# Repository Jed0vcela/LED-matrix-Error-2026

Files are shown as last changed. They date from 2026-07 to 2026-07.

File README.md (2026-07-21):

# LED Matrix Handheld — herní konzole s více hrami

Kapesní zařízení s LED maticí 32×16, postavené na Raspberry Pi Pico (RP2040)
s MicroPythonem. Samotné zařízení nabízí přes 20 vestavěných her a
pomůcek; víc zařízení lze propojit řetězcem po UART pro hry pro dva hráče
a sdílené režimy. K desce lze navíc připojit externí gamepad.
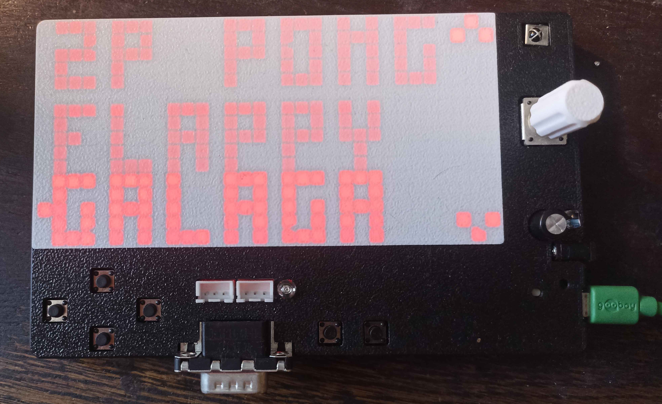
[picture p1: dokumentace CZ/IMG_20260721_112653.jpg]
popis obrázku


## Co to umí

- **20+ vestavěných her**: Snake, Breakout, uhýbačka ve stylu Flappy Bird,
  zjednodušená Galaga a Asteroids (obě s "megastřelou" po podržení
  tlačítka), Frogger, test reflexů, Missile Command, závodní uhýbač ve 4
  pruzích, běžecká hra ve stylu T-Rex se skutečnou skokovou fyzikou,
  paměťová hra ve stylu Simon a simulace rozvážejícího výtahu s plným
  rizikovým "MLG" režimem (detaily viz dokumentace firmware)
- **Podpora pro dva hráče** přes jednoduchý řetězec po UART — žádné
  párování, žádné adresování, stačí propojit zařízení TX→RX za sebou.
  Zahrnuje 2P Snake, 2P Pong, 2P Tron (light cycles) a sdílené 2P Malování /
  2P Game of Life
- **Pomůcky**: volné kreslení, Conwayova hra Life, hodiny, stopky, režim
  šetřiče displeje a nastavení (ruční nebo automatický jas podle
  světelného čidla, hodiny a přepínač zobrazení skóre po konci hry)
- **Senzory**: IR přijímač (vstup z dálkového ovladače, protokol NEC) a
  fotodioda (automatický jas podle okolního světla)
- **Externí gamepad** přes 9pinový D-sub konektor (pinout kompatibilní s
  Atari) — viz [HW.md](dokumentace%20CZ/HW.md)

## Návrhové nástroje

- **PCB** je nakreslené v [KiCad](https://www.kicad.org/) — je to zdarma a
  open-source, takže si projekt může kdokoliv doma otevřít, prohlédnout a
  upravit bez placené licence.
- **3D návrh** (krabička apod.) je vytvořený v Solidworks. Díly určené k
  3D tisku jsou ale exportované i jako `.STL` — to je běžný formát, se
  kterým si poradí prakticky jakýkoliv slicer/3D tiskárna, i bez Solidworks.

Detaily k oběma najdeš v [HW.md](dokumentace%20CZ/HW.md).

## Dokumentace

Kompletní rozpis každé hry a nastavení: **[FW_v1.0.md](dokumentace%20CZ/FW/v1.0/FW_v1.0.md)**

Zapojení, piny, gamepad a jak používat IR přijímač / fotodiodu:
**[HW.md](dokumentace%20CZ/HW.md)**

Popis podpůrných zdrojových souborů (co jde spustit samostatně, jak se dají
upravovat): **[ZDROJOVE_KODY.md](dokumentace%20CZ/ZDROJOVE_KODY.md)**

## Jak začít

1. **Nainstaluj Thonny** (IDE, kterým se kód MicroPythonu píše/nahrává do
   zařízení): [thonny.org](https://thonny.org/)
2. **Nahraj firmware do zařízení**: 
   [Jak nahrát soubory do zařízení (YouTube)](https://youtu.be/NCa7N6zXSKU?si=G6rsxXgdZRCBtUNG)
3. Pokud si stavíš vlastní zařízení od nuly, zapoj hardware podle
   **[HW.md](dokumentace%20CZ/HW.md)**.
4. Pro hry pro dva hráče propoj UART druhého zařízení podle
   [HW.md](dokumentace%20CZ/HW.md#propojení-pro-více-hráčů-řetězec) a zapni
   obě zařízení.

## Struktura repozitáře

```
README.md                          <- tenhle soubor (v rootu)
dokumentace CZ/
  HW.md                            <- zapojení hardwaru, gamepad, PCB/3D, IR/fotodioda
  ZDROJOVE_KODY.md                 <- popis podpůrných zdrojových souborů
  obrazky/                         <- obrázky použité v .md souborech
  FW/
    v1.0/
      FW_v1.0.md                   <- kompletní dokumentace firmware v1.0
    v1.1/ (do budoucna)
      FW_v1.1.md
main.py                            <- zdrojový kód firmware (doplnit / dle verze)
```

Každá verze firmware má vlastní složku a vlastní dokumentaci, takže i starší
verze zůstanou zdokumentované i po přidání novějších. Mezi jednotlivými
`.md` soubory se dá procházet přes odkazy přímo v textu.

## Aktuální verze firmware

**v1.0** — kompletní dokumentace her a nastavení je v
[FW_v1.0.md](dokumentace%20CZ/FW/v1.0/FW_v1.0.md).

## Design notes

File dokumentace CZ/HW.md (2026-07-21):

[⬅ Zpět na README](../README.md) · [Dokumentace firmware v1.0 →](FW/v1.0/FW_v1.0.md) · [Popis zdrojových souborů →](ZDROJOVE_KODY.md)

# Hardwarová dokumentace

Popisuje fyzické zapojení, návrhové nástroje a dvě "chytré" periferie (IR
přijímač a fotodioda).

## Přehled

- **Mikrokontrolér**: Raspberry Pi Pico / RP2040, MicroPython
- **Displej**: LED matice 32×16, multiplexovaná, řízená přes PIO (viz níže)
- **Vstup**: 6 tlačítek (nahoru, dolů, vlevo, vpravo, Fire1, Fire2) +
  1 rotační enkodér se vestavěným tlačítkem, plus volitelný externí gamepad
- **Propojení pro více hráčů**: řetězec (daisy-chain) po UART mezi zařízeními
  (viz níže)
- **Navíc**: IR přijímač (dálkové ovládání, protokol NEC), fotodioda
  (měření okolního světla pro automatický jas), reálný čas (interní RTC
  RP2040 přes `machine.RTC()`)

## Návrhové nástroje

- **PCB** je nakreslené v **KiCad**. KiCad je zdarma a open-source, takže
  projekt (schéma i desku) může kdokoliv otevřít doma, prohlédnout si ho a
  rovnou upravit — není potřeba žádná placená licence ani export do
  proprietárního formátu.
- **3D návrh** (krabička, mechanické díly) je nakreslený v **Solidworks**.
  Díly určené k 3D tisku jsou ale exportované i jako **`.STL`** — to je
  standardní formát pro 3D tisk, který přečte prakticky každý slicer i bez
  Solidworks.

## Co je GPIO

GPIO ("General Purpose Input/Output") je obecný digitální pin
mikrokontroléru, který jde v softwaru nastavit jako vstup nebo výstup a číst
z něj/zapisovat do něj logickou 0 nebo 1. Některé GPIO piny na RP2040 mají
navíc i **ADC** funkci — umí kromě digitálního 0/1 změřit i analogové napětí
(0–3,3 V). Právě tahle dvojí schopnost (digitální i analogové čtení na
stejném fyzickém pinu) je důvod, proč je GP27 níže v tabulce zajímavý — dá
se použít jak na jednoduché zapnuto/vypnuto ovládání něčeho externího, tak
na měření analogové úrovně nějakého vnějšího signálu.

## Kompletní zapojení pinů (RP2040)

| Pin | Funkce |
|---|---|
| GP0 | IR_RX (IR přijímač) |
| GP1 | row_latch |
| GP2 | row_clk |
| GP3 | row_mosi |
| GP4 | encoder B |
| GP5 | IR_TX (IR vysílač) |
| GP6 | encoder A |
| GP7 | Iset1 (LSB pro řízení jasu displeje) |
| GP8 | TX (pro multiplayer) |
| GP9 | RX (pro multiplayer) |
| GP10 | Iset2 (pro řízení jasu displeje) |
| GP11 | Iset3 (MSB pro řízení jasu displeje) |
| GP12 | LATCH (pro shift register sloupců) |
| GP13 | OE (output enable pro shift register sloupců) |
| GP14 | CLK (pro shift register sloupců) |
| GP15 | MOSI (pro shift register sloupců) |
| GP16 | button1 / fire1 (aktivní v log. 0) |
| GP17 | right (aktivní v log. 0) |
| GP18 | left (aktivní v log. 0) |
| GP19 | down (aktivní v log. 0) |
| GP20 | up (aktivní v log. 0) |
| GP21 | button2 / fire2 (aktivní v log. 0) |
| GP22 | tlačítko enkodéru |
| GP25 | onboard LED (bliká souběžně s přijímaným IR signálem, jen pro ladění) |
| GP26 | volný pin |
| GP27 | vyvedeno na 9pinový D-sub, umí digitální i ADC — viz sekce o gamepadu níže |
| GP28 | ADC, připojeno na fotodiodu — viz sekce o fotodiodě níže |

Tlačítka (GP16–GP21, GP22) se čtou jako **aktivní v log. 0** (stisknuto =
pin čte 0) — jsou tedy zapojená s pull-upem a spínačem, který při stisku
stáhne pin na zem.

Pár doplňujících technických detailů k vybraným pinům:

- **GP0** (IR přijímač) — digitální vstup, běžný IR demodulátor na 38 kHz
- **GP28** (fotodioda) — jde o ADC kanál **ADC2**
- **GP8/GP9** (řetězec pro více hráčů) — UART1, 115200 baud, 8N1

⚠️ **Známá chyba v návrhu desky**: rotační enkodér se při návrhu omylem
zapomněl připojit k Raspberry Pi Pico, takže se musel na hotové desce
zapojit ručně (mimo původní návrh DPS). Zapojení podle tabulky výše (GP4 =
B, GP6 = A, GP22 = tlačítko) ale odpovídá tomu, jak je to nakonec skutečně
zadrátované — detail ručního zapojení je na fotkách ve složce
[`obrazky/`](obrazky/).

## Externí gamepad (9pinový D-sub, pinout Atari)

K desce lze připojit externí gamepad přes **9pinový D-sub konektor** se
stejným pinoutem, jaký používaly ovladače konzole **Atari** — takže by na
desku měl jít připojit i leckterý originální/dobový Atari ovladač. Tlačítka
na gamepadu jsou zapojená **paralelně** k odpovídajícím tlačítkům přímo na
desce, takže elektricky jde jen o druhé místo ovládání téhož vstupu:
firmware nijak nepozná, jestli bylo zmáčknuté tlačítko na desce, nebo to
odpovídající na gamepadu, a pokud je stisknuté aspoň jedno z nich, vstup se
vyhodnotí jako stisknutý (log. 0 "vyhrává").

Konektor navíc vyvádí i dva signály navíc, nad rámec samotných tlačítek:

- **GP27** — nevyužitý GPIO pin, vyvedený na konektor, s funkcí digitálního
  I/O i **ADC**. Dá se tedy použít jak k jednoduchému zapnutí/vypnutí něčeho
  externího, tak k měření analogové úrovně nějakého vnějšího signálu. Pin má
  v sérii **1kΩ rezistor** kvůli větší odolnosti proti zkratu (kdyby se na
  něj omylem připojilo něco, co by se pokusilo pin natvrdo zkratovat na
  napájení nebo zem, rezistor omezí proud a ochrání pin/desku).
- **+5V** — na konektoru je vyvedené i napájecí napětí +5V, které lze použít
  k napájení připojené externí periferie (není tedy potřeba pro periferii
  řešit vlastní zdroj).

## Propojení pro více hráčů (řetězec)

Zařízení jsou propojená v řetězci po UART, TX jednoho zařízení do RX
dalšího:

```
Zařízení A  TX(GP8) ──► RX(GP9)  Zařízení B  TX(GP8) ──► RX(GP9)  Zařízení C ...
```

Hru reálně musí spustit jen **poslední** zařízení v řetězci — dřívější
zařízení mohou jen sedět v menu na obrazovce **BTN TEST**, která průběžně
přeposílá jejich vlastní stav tlačítek dál řetězcem. Poslední zařízení
kombinuje svá vlastní tlačítka s tím, co mu bylo přeposláno, a podle toho
běží hry pro dva hráče (2P Snake, 2P Pong, 2P Tron) nebo sdílené režimy
(2P Paint, 2P Life). Žádné vyjednávání/adresování mezi zařízeními neprobíhá
— ten, kdo fyzicky spustil hru pro dva hráče, je vždy "hráč 1", a cokoliv
přijde po řetězci, je vždy "hráč 2".

## Multiplexování LED matice a stmívání

Displej funguje na principu **multiplexování** — v jednu chvíli reálně
svítí vždy jen jeden řádek, ale řádky se přepínají tak rychle, že díky
setrvačnosti oka vypadá výsledek jako celý stálý obrázek najednou. Celé
časování řeší dva stavové stroje **PIO** (Programmable I/O v RP2040) — běží
tedy nezávisle na hlavním procesoru a jeho zatížení, takže obraz
neproblikává ani když CPU zrovna počítá něco náročnějšího. Jeden stavový
stroj nasype data pro sloupce do posuvného registru, druhý mezitím
přepočítá výběr řádku — a kvůli zamezení "duchů" (přechodovému prosvitu
špatného řádku, zatímco se do sloupců teprve nahrávají nová data) se výběr
řádku pokaždé nejdřív na okamžik úplně vynuluje, než se nastaví ten
skutečný.

Stmívání funguje na dvou nezávislých úrovních:

- **Jednotlivé body** (úrovně "zhasnuto / tlumeně / jasně") se řeší přímo
  časováním multiplexu — každý bod se v opakujícím se 4fázovém cyklu buď
  zobrazuje pořád (plný jas, 100 % snímků), nebo jen v jedné ze 4 fází
  (tlumeně, 25 % snímků), nebo vůbec.
- **Celkový jas celého displeje** (0–7) se nastavuje jinak — 3 digitální
  GPIO piny (`Iset1/2/3`) tvoří dohromady 3bitové číslo, které mimo tenhle
  software (už na desce) nastavuje referenční proud pro LED. Nejde tedy o
  další úroveň PWM navíc, ale o přímou změnu velikosti proudu, kterým jsou
  rozsvícené LED buzené — nezávisle na tom, jestli zrovna svítí "tlumeně"
  nebo "jasně" podle bodu výše.

Podrobný popis obou mechanismů (a jak přesně PIO kód pracuje) je v
[ZDROJOVE_KODY.md](ZDROJOVE_KODY.md#led_matrix_piopy).

## Použití IR přijímače

Firmware obsahuje IR přijímač s protokolem NEC na GP0. Aktuálně ho využívá
jen **SNAKE**, kde může řídit hada jako alternativu k tlačítkům. Namiř na
přijímač běžný dálkový ovladač s protokolem NEC (má ho spousta levných
univerzálních/TV ovladačů, typicky přiložených k levným RGB LED pásкům).

Konkrétní namapované kódy tlačítek (viz `process_ir()` v `main.py`):

| Kód příkazu (NEC) | Tlačítko na ovladači | Efekt |
|---|---|---|
| `0x0B` | nahoru | otočí hada (jako Fire1/Fire2 — ne absolutní směr jako fyzická šipka) |
| `0x0F` | dolů | otočí hada opačným směrem |
| `0x49` | vlevo | otočí hada stejným směrem jako "nahoru" |
| `0x4A` | vpravo | otočí hada stejným směrem jako "dolů" |
| `0x01` | hvězdička (`*`) | ztlumit displej |
| `0x0A` | mřížka (`#`) | zesvětlit displej |
| `0x0D` | OK | (kód je definovaný, ale zatím se nikde nepoužívá) |

Opakovaný kód, který dálkový ovladač posílá při podrženém tlačítku, se
ignoruje (`IR_CMD` se použije jen jednou za skutečný, ne opakovaný, stisk).

Piny GP0 (příjem) a GP5 (vysílání, zatím nevyužité — viz
[ZDROJOVE_KODY.md](ZDROJOVE_KODY.md#ir_necpy)) jsou popsané podrobněji v
dokumentaci zdrojových souborů.

## Použití fotodiody (automatický jas)

Fotodioda na GP28 umožňuje zařízení samo přizpůsobovat jas displeje podle
okolního světla, místo ručního nastavování. Je zapojená ve
**fotovoltaickém módu** (bez předpětí) — v tomhle zapojení fotodioda sama
generuje napětí úměrné světlu, ale s **logaritmickou** odezvou na intenzitu
světla, ne lineární. Prakticky to znamená, že fotodioda je citlivá na malé
změny jasu v šeru (kde logaritmus roste rychle) a zároveň nesaturuje na
plné slunci (kde logaritmus roste už jen pomalu) — jedním zapojením tak jde
rozumně pokrýt jak velmi tmavé, tak velmi jasné prostředí, aniž by bylo
potřeba přepínat rozsah. To se označuje jako zvětšení **dynamického
rozsahu** čidla.

- Jdi do **SETTINGS**, vyber pole s režimem jasu a otočením enkodéru přepni
  z `MAN` na `AUTO`
- V režimu AUTO se syrová hodnota z ADC přemapuje na jas zhruba takhle:
  - syrová hodnota ≤ 3000 → minimální jas
  - syrová hodnota ≥ 7000 → maximální jas
  - lineárně mezi tím
- Tohle přemapování není myšlené jako přesné — je to hrubá, levná
  (počítaná bitovým posunem) interpolace, odhadnutá od oka, ne podle
  změřené křivky v luxech. Pokud to na tvém typickém osvětlení působí moc
  tmavě/světle, právě tahle dvě prahová čísla (3000 / 7000) jsou to, co má
  smysl doladit.
- Automatický jas se přepočítává zhruba každých 300 ms a funguje i během
  hraní, ne jen v obrazovce Nastavení.

### Analýza signálu z fotodiody (`adc_sampler.py`)

Ve zdrojových kódech je i pomocný skript **`adc_sampler.py`**, který měří
hodnoty na fotodiodě relativně rychle (mnohem rychleji, než firmware
potřebuje pro automatický jas) a výsledky vypisuje do konzole v **CSV**
formátu. Takový výstup jde zkopírovat a otevřít třeba v Excelu a udělat z
něj graf — díky tomu jde odhalit i jevy, které lidské oko normálně nezachytí,
například světlo, které bliká (např. kvůli PWM stmívání) tak rychle, že to
oko vnímá jako stále svítící, ale na grafu z rychlého vzorkování je blikání
jasně vidět. Podrobnější popis viz
[`ZDROJOVE_KODY.md`](ZDROJOVE_KODY.md#adc_samplerpy).

## Co v tomhle dokumentu chybí

- Chybí poznámky ke krabičce/mechanické montáži.
- Chybí přesná specifikace napájení (napětí/konektor napájecího zdroje celé
  desky).
- Přesné přiřazení jednotlivých signálů (6 tlačítek, +5V, GP27, GND) k
  fyzickým číslům pinů 1–9 na D-sub konektoru není potvrzené — výše je
  jen jejich seznam, ne mapování na konkrétní čísla pinů konektoru.
- Přesný analogový mechanismus, kterým piny Iset1/2/3 na desce mění
  referenční proud (např. konkrétní zapojení odporové sítě), není součástí
  žádného `.py` souboru, takže to tu není popsané — jde o čistě hardwarovou
  věc na desce/schématu.

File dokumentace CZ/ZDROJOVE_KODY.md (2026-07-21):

[⬅ Zpět na README](../README.md) · [Hardwarová dokumentace](HW.md) · [Dokumentace firmware v1.0](FW/v1.0/FW_v1.0.md)

# Popis zdrojových souborů

Firmware `main.py` (viz [FW_v1.0.md](FW/v1.0/FW_v1.0.md) pro popis her a
nastavení) importuje několik samostatných modulů, které mají každý na
starosti jednu konkrétní část hardwaru. Tenhle dokument popisuje **tyhle
podpůrné moduly** — ne samotné hry, ty už jsou popsané ve firmware
dokumentaci.

Každý z nich jde **spustit i samostatně** (nahraný a puštěný sám v Thonny,
bez zbytku firmware — hodí se to při ladění konkrétní periferie) a jde
normálně otevřít a upravit v Thonny jako kterýkoliv jiný `.py` soubor.

---

## `photodiode.py`

Jednoduchý samostatně spustitelný soubor pro čtení fotodiody na **GP28**.

- **Konfigurace pull rezistoru** nahoře v souboru (proměnná `PULL`) — lze
  přepnout mezi žádným pull rezistorem, pull-up nebo pull-down podle toho,
  jak je fotodioda v konkrétním zapojení zadrátovaná (bez rezistoru = plovoucí
  vstup, nejcitlivější; pull-down bývá obvykle nejlepší volba pro holou
  fotodiodu bez externího rezistoru — tma = 0 V, světlo = vyšší napětí).
- **Funkce k použití z jiného kódu**:
  - `read_raw()` — vrátí syrovou 16bitovou hodnotu ADC (0–65535)
  - `read_voltage()` — totéž převedené na napětí (0,0–3,3 V)
  - `read_percent()` — totéž jako 0–100 %
- **Spuštění samostatně**: každých 500 ms (`INTERVAL_MS`) vypíše do konzole
  syrovou hodnotu, napětí a procenta. Zastavení přes Ctrl-C.
- Tohle je jednodušší a pomalejší nástroj než `adc_sampler.py` (viz níže) —
  hodí se spíš na rychlou kontrolu "svítí/nesvítí něco na fotodiodu", ne na
  zachycení rychlých změn.

Poznámka: komentář v souboru říká "GP28 = ADC channel 0" — ve skutečnosti je
GP28 kanál **ADC2** (GP26=ADC0, GP27=ADC1, GP28=ADC2). Na funkčnost to
nemá vliv (kód si kanál najde sám podle čísla pinu), je to jen nepřesnost
v popisném komentáři.

---

## `adc_sampler.py`

Rychlejší a přesnější sourozenec `photodiode.py` — místo průběžného
vypisování **nejdřív nasbírá pevný počet vzorků do předalokovaného pole a
až pak je celé vypíše**, aby samotné měření neovlivňovalo žádné
alokování paměti, tisk na obrazovku ani přerušení.

- **Konfigurace** nahoře v souboru:
  - `NUM_SAMPLES = 1000` — kolik vzorků nabrat
  - `INTERVAL_US = 1000` — rozestup mezi vzorky v mikrosekundách (1000 = 1 ms);
    nastavením na `0` se vzorkuje maximální možnou rychlostí (~500 kHz)
- **`capture(num, interval_us)`** — nasbírá vzorky do předalokovaných polí
  (`array` typu `H`/`I`, žádná alokace za běhu), buď v pevném intervalu
  (aktivní čekání do dalšího vzorku), nebo na maximální rychlost
- **`print_samples(n, show_time, show_voltage)`** — vypíše všechny
  zachycené vzorky ve formátu **CSV** (`index,time_us,raw[,voltage]`,
  s hlavičkovým komentářem `# ...` na začátku)
- **`print_stats(n)`** — vypíše min/max/průměr a skutečně dosaženou
  vzorkovací frekvenci
- **Samostatné spuštění**: nasbírá `NUM_SAMPLES` vzorků, vypíše statistiky a
  pak celý CSV výstup, zakončený řádkem `# END`

Výstup jde zkopírovat z konzole Thonny a vložit třeba do Excelu (Data →
Text do sloupců, oddělovač čárka) a udělat z něj graf. Díky rychlému
vzorkování jde odhalit i to, co lidské oko nezachytí — třeba světlo, které
ve skutečnosti bliká (např. kvůli PWM řízení jiného zdroje světla v
místnosti) tak rychle, že to oko vnímá jako trvale svítící, ale na grafu
z dostatečně rychlého vzorkování je blikání jasně vidět jako pravidelné
výkyvy hodnoty.

---

## `encoder.py`

Ovladač rotačního enkodéru s tlačítkem, dekódovaný přes **kvadraturu** (obě
hrany na obou fázových signálech A/B — 4× rozlišení oproti dekódování jen
jedné hrany).

- **Piny**: `ENC_A = GP6`, `ENC_B = GP4`, `ENC_SW = GP22` (tlačítko, aktivní
  v log. 0, s interním pull-upem)
- Zajímavý detail v kódu: konstruktor **schválně prohodí A a B**
  (`self._pin_a = machine.Pin(pin_b, ...)` a naopak) — je to oprava správného
  směru otáčení, která zůstala z ladění na reálném hardwaru. Fyzické
  zapojení (GP6=A, GP4=B) tím zůstává stejné, jen se to uvnitř softwarově
  "přehodí", aby otáčení doprava odpovídalo očekávanému směru.
- Dekódování běží na **hardwarových přerušeních** (IRQ) na obou hranách
  obou pinů — enkodér tedy reaguje okamžitě, nezávisle na tom, jak často
  hlavní kód volá jeho metody.
- **4 syrové kroky kvadratury = 1 mechanický cvakl** enkodéru (`_raw_steps`
  se akumuluje a teprve při `abs(...) >= 4` se promítne do `value`/`delta`).

### API

```python
enc = Encoder()
enc.value                     # aktuální pozice (int, může být záporná)
enc.value = 5                 # nastavení pozice (zároveň vynuluje delta)
enc.reset()                   # nastaví pozici na 0
enc.delta()                   # změna od posledního volání, pak se vynuluje
enc.pressed                   # True, pokud je tlačítko PRÁVĚ TEĎ drženo (syrový stav)
enc.was_pressed()             # True, pokud bylo tlačítko stisknuto od posledního volání
                               # (jednorázový příznak, čtením se maže)
enc.set_range(min, max, wrap=False)   # omezí/zabalí pozici do rozsahu
enc.deinit()                  # odregistruje přerušení
```

Poznámka k hlavnímu firmware: `main.py` má vlastní obal `EncoderEdge` nad
touhle třídou, který dělá **vlastní** hranovou detekci stisku tlačítka
(pollováním `enc.pressed`), místo aby se spoléhal přímo na `was_pressed()`
téhle třídy — ukázalo se to jako spolehlivější řešení jednoho okrajového
případu (hra se občas hned po výběru z menu sama ukončila). Metoda
`was_pressed()` v tomhle souboru je nicméně sama o sobě navržená jako
jednorázový příznak nastavovaný v přerušení, takže by principiálně měla
fungovat správně i bez toho obalu — příčina toho konkrétního chování nebyla
nakonec s jistotou dohledaná.

---

## `ir_nec.py`

Obsahuje dvě oddělené věci v jednom souboru:

### Třída `NEC` — příjem IR dálkového ovladače

- **Piny**: `IR_RX_PIN = GP0` (příjem, aktivní v log. 0, pull-up), `GP5`
  je v komentáři zmíněný jako **IR-TX** (vysílání) přes PIO1 SM0, ale v
  tomhle souboru **není vysílání implementované** — GP5 je zatím jen
  rezervovaný/zadrátovaný pin pro budoucí použití
- Onboard LED na **GP25** bliká synchronně s přijímaným IR signálem — hodí
  se to jako vizuální potvrzení "něco se přijímá", i bez připojeného PC
- Dekóduje protokol **NEC** čistě měřením délek pulzů na hraně přerušení
  (leader pulz, pak 32 bitů adresa/~adresa/příkaz/~příkaz s kontrolou
  negace), včetně rozpoznání "repeat" rámce (držení tlačítka na dálkovém
  ovladači)
- **Použití**:
  ```python
  ir = NEC(pin_num=0, callback=my_fn)   # callback(addr, cmd, repeat)
  # nebo bez callbacku:
  ir = NEC(pin_num=0)
  ir.update()          # zavolat pravidelně (zpracuje nasbírané hrany)
  event = ir.poll()    # vrátí (addr, cmd, repeat) nebo None
  ```

### Třída `MatrixCurrent` — celkový jas displeje

Řídí **3 digitální GPIO piny** (`Iset1=GP7`, `Iset2=GP10`, `Iset3=GP11`),
které dohromady tvoří 3bitové číslo 0–7 (Iset1 = LSB, Iset3 = MSB, všechny
piny v log. 1 = maximální jas). Tenhle 3bitový kód pak mimo tenhle
softwarový soubor (na desce) nastavuje referenční proud, kterým se řídí
celkový jas LED matice — přesný analogový mechanismus (např. odporová síť
apod.) není součástí tohoto `.py` souboru, je to už čistě hardwarová věc na
desce.

```python
current = MatrixCurrent()
current.set_level(5)     # 0 (min) - 7 (max)
current.get_level()
current.step_up()        # o úroveň výš (won't přetéct nad 7)
current.step_down()
current.toggle()         # přepne mezi úplným minimem a maximem
```

---

## `led_matrix_pio.py`

Nejsložitější modul — řídí LED matici 16×32 pomocí dvou stavových strojů
**PIO** (Programmable I/O v RP2040), plus dvě vlákna (Core 0 / Core 1).

### Piny

| Signál | Pin |
|---|---|
| row_mosi | GP3 |
| row_clk | GP2 |
| row_latch | GP1 |
| col_mosi | GP15 |
| col_clk | GP14 |
| col_latch | GP12 |
| col_OE (aktivní v log. 0) | GP13 |

### Princip multiplexování

Displej se zobrazuje po jednotlivých řádcích (multiplexování — viz i
[HW.md](HW.md#multiplexování-led-matice-a-stmívání)):

1. **SM0** (`col_program`, 8 MHz) nejdřív zhasne výstup (OE=1), pošle
   signál SM1, ať připraví "slepý" řádek (všechny řádky odpojené) a počká,
   až SM1 potvrdí
2. Nasype 32 bitů dat pro sloupce do posuvného registru a zacvakne je
   (`col_latch`)
3. Pošle signál SM1, ať tentokrát připraví **skutečný** vybraný řádek, počká
   na potvrzení
4. Zapne výstup (OE=0) a chvíli počká (řádek svítí)
5. Opakuje se pro další řádek

**SM1** (`row_program`, 2 MHz) jen čeká na signál od SM0, nasype 16 bitů
výběru řádku a zacvakne je (`row_latch`) — volá se **dvakrát na řádek**
(jednou se slepým/nulovým výběrem, jednou se skutečným) právě kvůli kroku
2–3 výše, což zabraňuje "duchům" (ghosting) — přechodovému prosvítnutí
špatného řádku, zatímco se do sloupců teprve nahrávají nová data.

### Stmívání (3 úrovně na bod)

Firmware si interně drží dva bitové obrazy za snímek — `_full` (všechny
body úrovně ≥1) a `_bright` (jen body úrovně 2). Zobrazovací cyklus má
4 fáze (`_GS_CYCLE = (_full, _bright, _bright, _bright)`):

- Bod úrovně **2** (plný jas): je v `_bright`, takže svítí ve všech
  4 fázích → 100 % svitu
- Bod úrovně **1** (tlumeně): je jen v `_full`, které se použije jen
  1 ze 4 fází → **25 %** svitu (ne 50 %, jak by se dalo čekat z názvu
  "half brightness" v úvodním komentáři souboru — to je drobná nepřesnost
  v komentáři, skutečné chování podle kódu je 25 %)
- Bod úrovně **0**: nikde, nesvítí vůbec

Tohle se řeší čistě časováním multiplexu (viz
[HW.md](HW.md#multiplexování-led-matice-a-stmívání)) — je to jiná věc než
celkový jas přes `MatrixCurrent`/Iset piny, který mění fyzický proud, ne
poměr času svícení.

### Souřadnice řádků jsou uvnitř otočené

`set_pixel(row, col, level)` si interně ukládá do `_back[ROWS-1-row][col]`
— řádek 0 podle volajícího kódu (main.py, hry) tedy fyzicky odpovídá
**poslednímu** řádku vnitřního bufferu. To znamená, že displej je fyzicky
zapojený "vzhůru nohama" vůči tomu, jak si ho vnitřně ukládá framebuffer, a
ovladač to sám neviditelně kompenzuje — volající kód (main.py) se o tohle
nemusí starat, řádek 0 je vždy nahoře, jak by se čekalo.

### Core 0 / Core 1

- **Core 1** běží nekonekonečnou smyčku (`_core1_loop`), která pořád dokola
  volá `fill_fifo()` (posílá další snímek do PIO) a mezi tím i volitelný
  **callback** zaregistrovaný přes `register_callback(fn)` — přesně tady se
  do multiplexovací smyčky "zavěsí" `token_ring.py` (jeho `_tick()` metoda),
  aby síťová komunikace běžela nezávisle na tom, co dělá hlavní kód her na
  Core 0.
- **Core 0** (hlavní kód her) jen kreslí do back-bufferu (`set_pixel`,
  `clear`, `fill`, `fill_rect`, ...) a zavolá `show()`, když je snímek
  hotový — `show()` jen přepočítá `_full`/`_bright` z back-bufferu, samotné
  posílání do PIO běží pořád na Core 1 na pozadí.

### API

```python
from led_matrix_pio import *
start()                         # spustí PIO + Core 1 smyčku
set_pixel(row, col, level)      # level: 0=off, 1=tlumeně, 2=plně
get_pixel(row, col)
clear()
fill(level=2)
show()                           # přepočítá _full/_bright z back-bufferu
draw_hline(row, col, w, level)
draw_vline(col, row, h, level)  # pozor - row/col je tu v OPAČNÉM pořadí než u draw_hline!
draw_rect(row, col, h, w, level)
fill_rect(row, col, h, w, level)
scroll_left(n) / scroll_right(n)
register_callback(fn)           # zaregistruje funkci volanou na Core 1 mezi snímky
stop()
```

⚠️ **Pozor na pořadí parametrů `h, w`** (výška, pak šířka) u `fill_rect` a
`draw_rect` — je to jiné pořadí, než by člověk čekal ("šířka, výška"), a
zrovna v tomhle souboru se navíc `draw_hline`/`draw_vline` neshodují ani
samy mezi sebou (`draw_vline` má `col` a `row` prohozené oproti
`draw_hline`). Při čtení `main.py` jsem narazil na **tři místa, kde jsou
parametry `fill_rect` pravděpodobně prohozené** oproti tomuhle skutečnému
pořadí:

- sloupcový ukazatel jasu v **SETTINGS** (vykreslí se jako 3 řádky × 2
  sloupce místo zamýšlených ~2 řádků × 3 sloupce)
- záblesk megastřely v **GALAGA** (šířka/výška výbuchu prohozené — většinou
  neviditelné, protože výbuch bývá symetrický, ale u okraje displeje by se
  mohl neplánovaně oříznout v jiném rozměru, než by měl)
- kabina výtahu v **ELEVATOR** (vykreslí se jako 1 sloupec × 2 řádky místo
  zamýšlených 2 sloupců × 1 řádek)

Žádné z toho nespadne ani se nezasekne, jde jen o drobné vizuální
nepřesnosti — zmiňuji to tu, protože bez skutečného zdrojového kódu tohohle
souboru nebylo možné poznat, že se jedná o mou vlastní chybu při psaní
`main.py`, ne o neověřený předpoklad.

---

## `token_ring.py`

Kompletní implementace řetězcového (daisy-chain) propojení pro víc hráčů
přes UART1 (**TX = GP8, RX = GP9**, 115200 baud). Tohle je jádro toho, jak
funguje multiplayer popsaný v [HW.md](HW.md#propojení-pro-více-hráčů-řetězec).

### Formát paketu (11 bajtů)

| Bajt | Význam |
|---|---|
| 0 | sync1 (`0xAA`) |
| 1 | sync2 (`0x55`) |
| 2 | ORIGIN — id zařízení, které paket vyslalo (poslední bajt `machine.unique_id()`) |
| 3 | HOP_COUNT — při každém přeposlání se zvýší o 1 |
| 4 | SEQ — pořadové číslo |
| 5 | FLAGS — rezervováno |
| 6 | BUTTONS — bit0=fire1, bit1=right, bit2=left, bit3=down, bit4=up, bit5=fire2 |
| 7–8 | PAYLOAD — rezervováno |
| 10 | CRC (XOR bajtů 2–9) |

Každé zařízení navíc jednou za vteřinu (výchozí `heartbeat_ms`) posílá i
čitelný textový řádek (`HB <id> <uptime> mem=... ring=... lat=... ...`) s
diagnostickými údaji — to není součást herního paketu, posílá se to vždy,
nezávisle na stavu řetězce, a přijaté řádky se vypisují do konzole s
prefixem `<<< `.

### Použití (z jiného kódu)

```python
from token_ring import TokenRing
ring = TokenRing()
ring.start()               # zaregistruje se do PIO smyčky (Core 1)
ring.send_buttons(byte)    # volat z hlavní smyčky, každý průchod
ring.get_state()           # {id_zařízení: byte_tlačítek, ...}
ring.get_info()            # (velikost řetězce, latence v ms)
ring.node_id()             # vlastní id tohoto zařízení
TokenRing.buttons_byte(fire1, right, left, down, up, fire2)  # sbalí stav do bajtu
TokenRing.unpack_buttons(byte)  # rozbalí bajt zpět na jednotlivé booleany
```

### Samostatné spuštění

Soubor jde spustit i sám o sobě — projde postupně několika kroky (surový
UART loopback test, test jednoho paketu, test heartbeatu, 10s syrový
monitor příchozích bajtů, a nakonec plnou smyčku s `ring.debug = True`, kde
se vypisuje každá odeslaná/přijatá/přeposlaná zpráva). Hodí se to hlavně na
ověření zapojení GP8/GP9 mezi dvěma zařízeními, než se zkouší cokoliv výš
(hry pro dva hráče apod.).

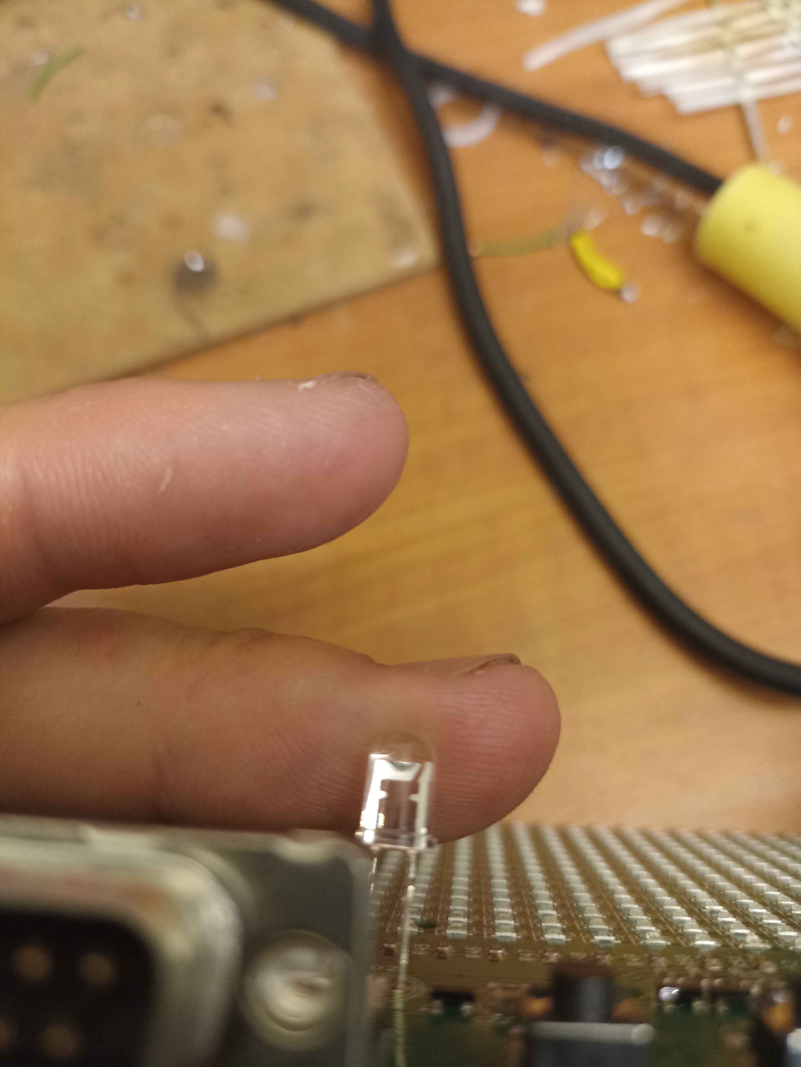
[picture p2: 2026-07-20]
navody, fotky/matrix/detail fotodiody.jpg

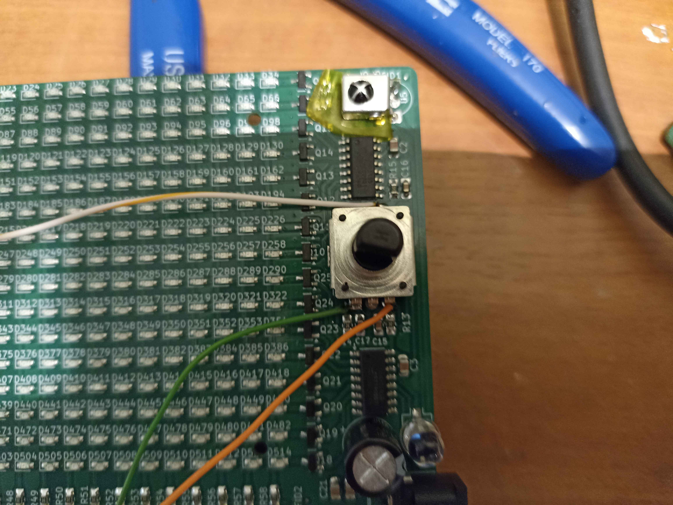
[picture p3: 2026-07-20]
navody, fotky/matrix/drátování enkodéru2.jpg

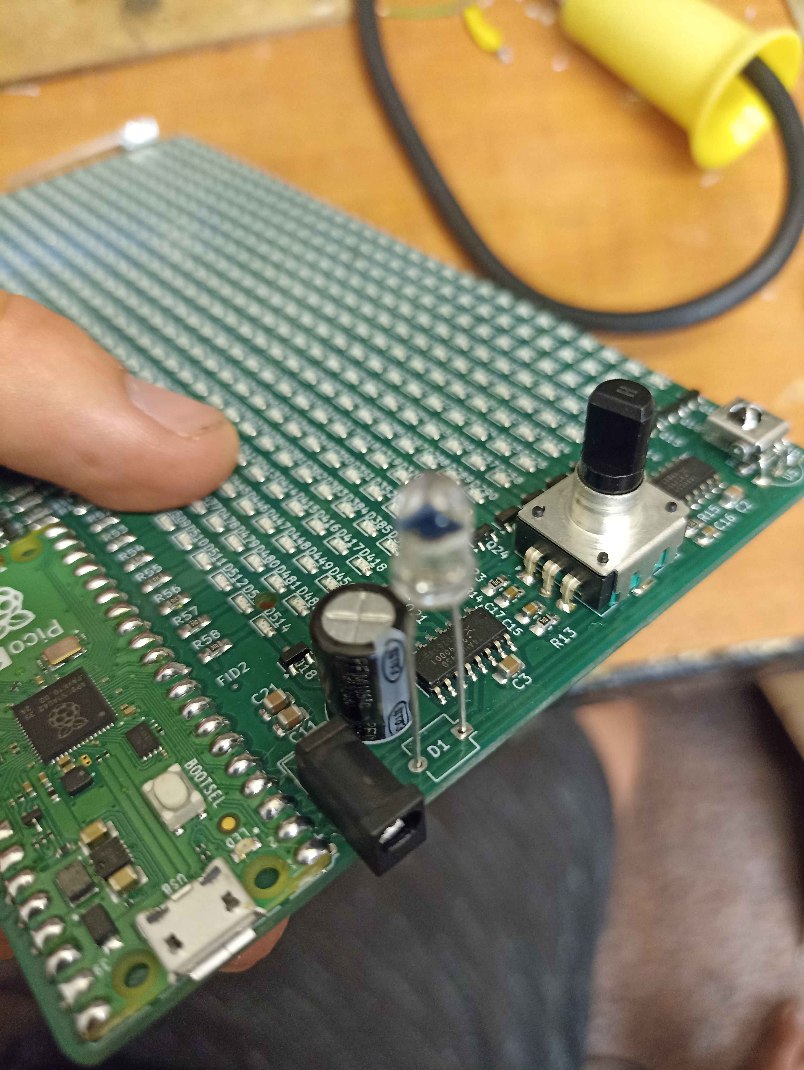
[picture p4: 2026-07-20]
navody, fotky/matrix/polarita kondenzátoru.jpg

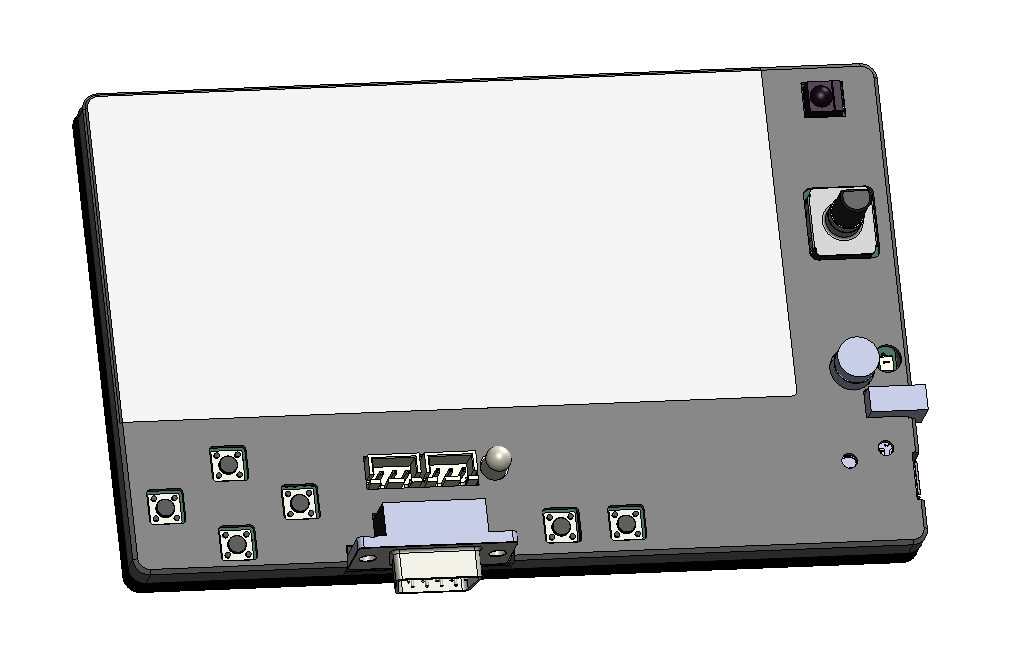
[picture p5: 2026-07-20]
3D files/enclosure/detail.png

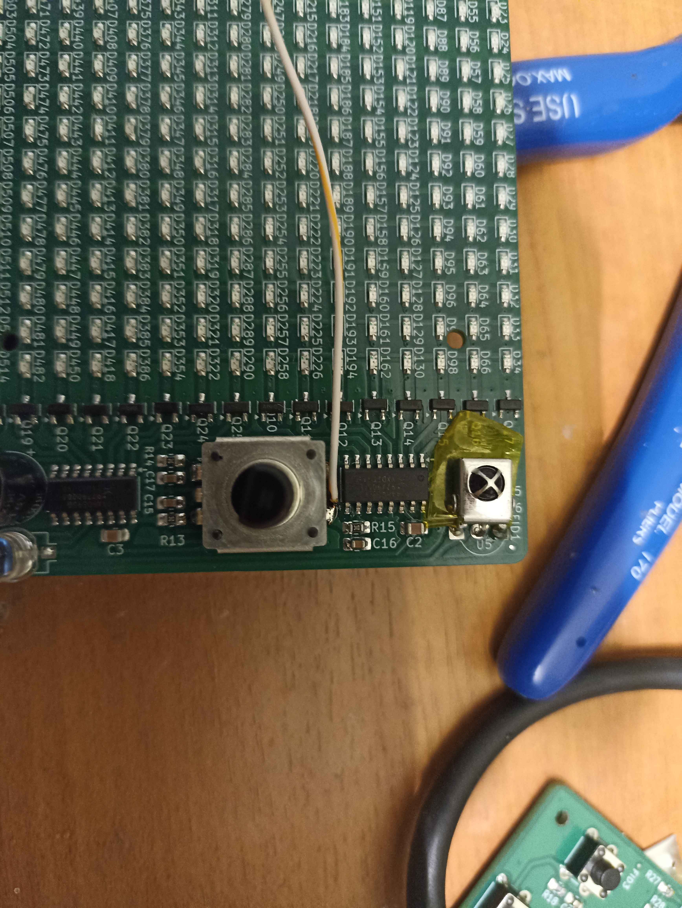
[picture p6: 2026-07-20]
navody, fotky/matrix/drátování enkodéru1.jpg

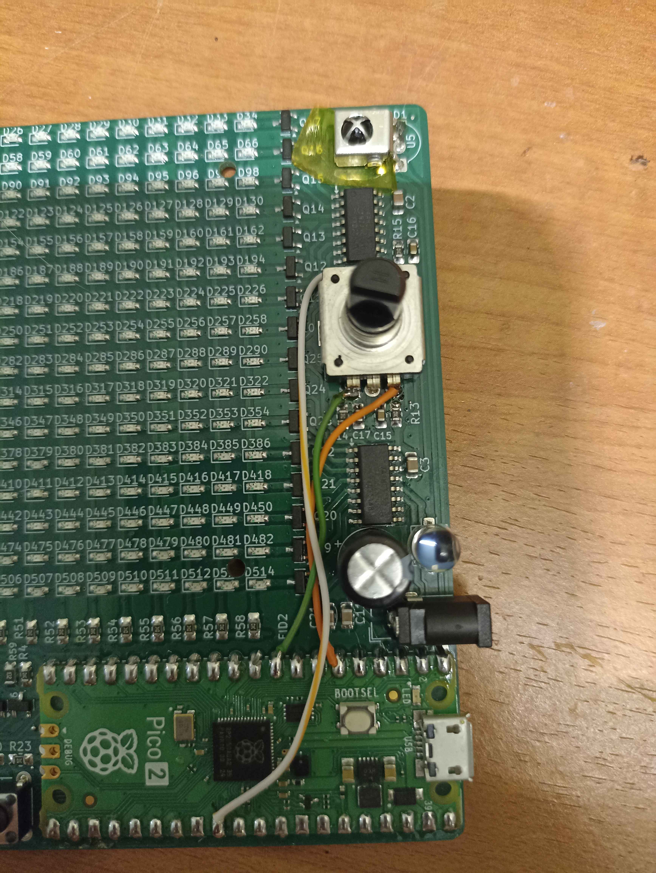
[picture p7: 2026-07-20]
navody, fotky/matrix/drátování enkodéru3.jpg

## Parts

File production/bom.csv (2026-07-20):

Designator | Footprint | Quantity | Value | LCSC Part #
A1 | RaspberryPi_Pico_SMD_HandSolder | 1 | RaspberryPi_Pico2
C1, C11, C2, C21, C3, C4 | 0805 | 6 | 1u
C10, C22, C6, C9 | 0805 | 4 | 10u
C12, C13, C14, C15, C16, C17, C18, C19, C20, C5 | 0805 | 10 | 100n
C8 | CP_Radial_D8.0mm_P3.50mm | 1 | C_Polarized
D1 | Osram_DIL2_4.3x4.65mm_P5.08mm | 1 | BPW34
D10, D100, D101, D102, D103, D104, D105, D106, D107, D108, D109, D11, D110, D111, D112, D113, D114, D115, D116, D117, D118, D119, D12, D120, D121, D122, D123, D124, D125, D126, D127, D128, D129, D13, D130, D131, D132, D133, D134, D135, D136, D137, D138, D139, D14, D140, D141, D142, D143, D144, D145, D146, D147, D148, D149, D15, D150, D151, D152, D153, D154, D155, D156, D157, D158, D159, D16, D160, D161, D162, D163, D164, D165, D166, D167, D168, D169, D17, D170, D171, D172, D173, D174, D175, D176, D177, D178, D179, D18, D180, D181, D182, D183, D184, D185, D186, D187, D188, D189, D19, D190, D191, D192, D193, D194, D195, D196, D197, D198, D199, D20, D200, D201, D202, D203, D204, D205, D206, D207, D208, D209, D21, D210, D211, D212, D213, D214, D215, D216, D217, D218, D219, D22, D220, D221, D222, D223, D224, D225, D226, D227, D228, D229, D23, D230, D231, D232, D233, D234, D235, D236, D237, D238, D239, D24, D240, D241, D242, D243, D244, D245, D246, D247, D248, D249, D25, D250, D251, D252, D253, D254, D255, D256, D257, D258, D259, D26, D260, D261, D262, D263, D264, D265, D266, D267, D268, D269, D27, D270, D271, D272, D273, D274, D275, D276, D277, D278, D279, D28, D280 | 0603 | 200 | LED_45deg
D2 | LED_D5.0mm_Clear | 1 | LED
D281, D282, D283, D284, D285, D286, D287, D288, D289, D29, D290, D291, D292, D293, D294, D295, D296, D297, D298, D299, D3, D30, D300, D301, D302, D303, D304, D305, D306, D307, D308, D309, D31, D310, D311, D312, D313, D314, D315, D316, D317, D318, D319, D32, D320, D321, D322, D323, D324, D325, D326, D327, D328, D329, D33, D330, D331, D332, D333, D334, D335, D336, D337, D338, D339, D34, D340, D341, D342, D343, D344, D345, D346, D347, D348, D349, D35, D350, D351, D352, D353, D354, D355, D356, D357, D358, D359, D36, D360, D361, D362, D363, D364, D365, D366, D367, D368, D369, D37, D370, D371, D372, D373, D374, D375, D376, D377, D378, D379, D38, D380, D381, D382, D383, D384, D385, D386, D387, D388, D389, D39, D390, D391, D392, D393, D394, D395, D396, D397, D398, D399, D4, D40, D400, D401, D402, D403, D404, D405, D406, D407, D408, D409, D41, D410, D411, D412, D413, D414, D415, D416, D417, D418, D419, D42, D420, D421, D422, D423, D424, D425, D426, D427, D428, D429, D43, D430, D431, D432, D433, D434, D435, D436, D437, D438, D439, D44, D440, D441, D442, D443, D444, D445, D446, D447, D448, D449, D45, D450, D451, D452, D453, D454, D455, D456, D457, D458, D459, D46, D460 | 0603 | 200 | LED_45deg
D461, D462, D463, D464, D465, D466, D467, D468, D469, D47, D470, D471, D472, D473, D474, D475, D476, D477, D478, D479, D48, D480, D481, D482, D483, D484, D485, D486, D487, D488, D489, D49, D490, D491, D492, D493, D494, D495, D496, D497, D498, D499, D5, D50, D500, D501, D502, D503, D504, D505, D506, D507, D508, D509, D51, D510, D511, D512, D513, D514, D52, D53, D54, D55, D56, D57, D58, D59, D6, D60, D61, D62, D63, D64, D65, D66, D67, D68, D69, D7, D70, D71, D72, D73, D74, D75, D76, D77, D78, D79, D8, D80, D81, D82, D83, D84, D85, D86, D87, D88, D89, D9, D90, D91, D92, D93, D94, D95, D96, D97, D98, D99 | 0603 | 112 | LED_45deg
J1, J3 | JST_XH_B3B-XH-A_1x03_P2.50mm_Vertical | 2 | Conn_01x03_Pin
J2 | DSUB-9_Pins_Horizontal_P2.77x2.84mm_EdgePinOffset4.94mm_Housed_MountingHolesOffset4.94mm | 1 | DE9_Pins_MountingHoles
J4 | BarrelJack_GCT_DCJ200-10-A_Horizontal | 1 | Barrel_Jack_Switch
Q1, Q2, Q3, Q4, Q5, Q6, Q7 | SOT-23 | 7 | 2N7002
Q10, Q11, Q12, Q13, Q14, Q15, Q16, Q17, Q18, Q19, Q20, Q21, Q22, Q23, Q24, Q25 | SOT-23 | 16 | AO3401A
R1, R27, R28, R29, R30, R31, R32, R33, R34, R35, R36, R37, R38, R39, R4, R40, R41, R42, R43, R44, R45, R46, R47, R48, R49, R50, R51, R52, R53, R54, R55, R56, R57, R58 | 0805 | 34 | 10k
R10, R11, R12, R5 | 0805 | 4 | 47
R13, R14, R15, R16, R17, R18, R21, R22, R23, R6 | 0805 | 10 | 22k
R19, R20, R24, R26, R59 | 0805 | 5 | 1k
R2, R3 | 0805 | 2 | 4k7
R25, R60 | 0805 | 2 | 2k2
R61, R62 | 0805 | 2 | 10
SW1 | RotaryEncoder_Alps_EC11E-Switch_Vertical_H20mm | 1 | RotaryEncoder_Switch_MP
SW2, SW3, SW4, SW5, SW6, SW7 | SW_PUSH_6mm_H4.3mm | 6 | SW_Push
U1, U4 | SSOP-24_3.9x8.7mm_P0.635mm | 2 | SCT2024CSSG
U2, U3 | SOIC-16_3.9x9.9mm_P1.27mm | 2 | 74AHC595
U5 | Vishay_MOLD-3Pin | 1 | TSOP45xx
U6 | SOT-223-3_TabPin2 | 1 | AMS1117-5.0

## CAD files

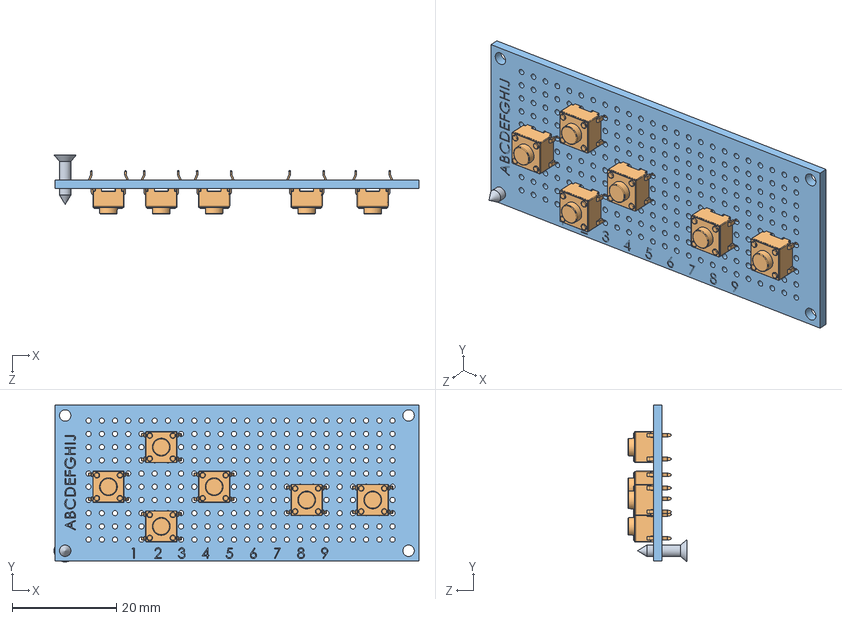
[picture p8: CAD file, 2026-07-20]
3D files/gamepad/gamepad.SLDASM
70.2 x 30.2 x 11.4 mm
Univerzální DPS 3x7cm, 240p
tactileswitch-short x 6
Vrut; 2,2x9,5

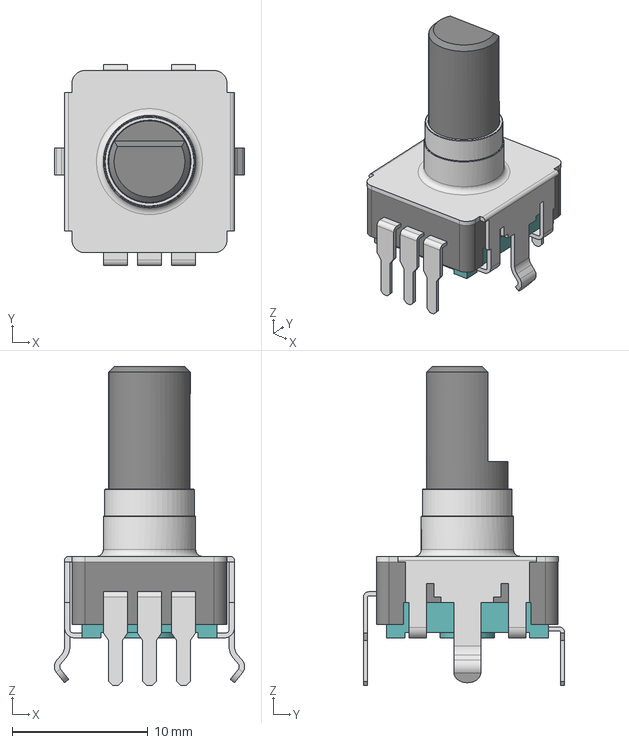
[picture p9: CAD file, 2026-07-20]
3D files/EC12E20-24P24C-SW.stp
14.0 x 14.8 x 23.5 mm

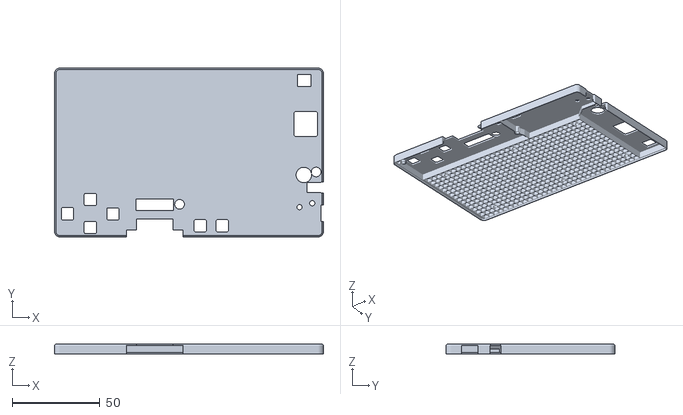
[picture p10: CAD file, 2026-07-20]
3D files/enclosure/top side.STL
153.2 x 96.2 x 5.80

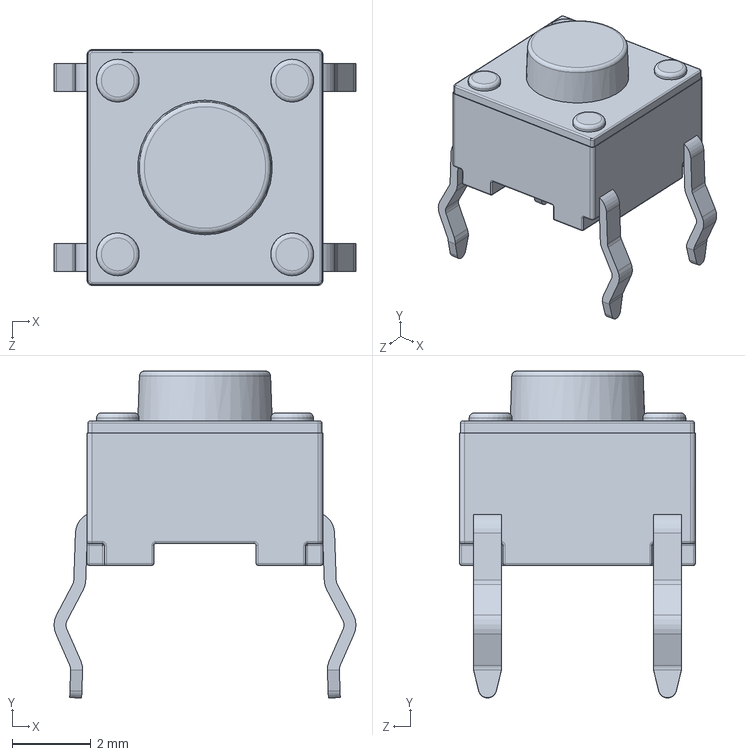
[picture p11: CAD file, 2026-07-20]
3D files/gamepad/tactileswitch-short.SLDPRT
7.69 x 8.33 x 6.01 mm

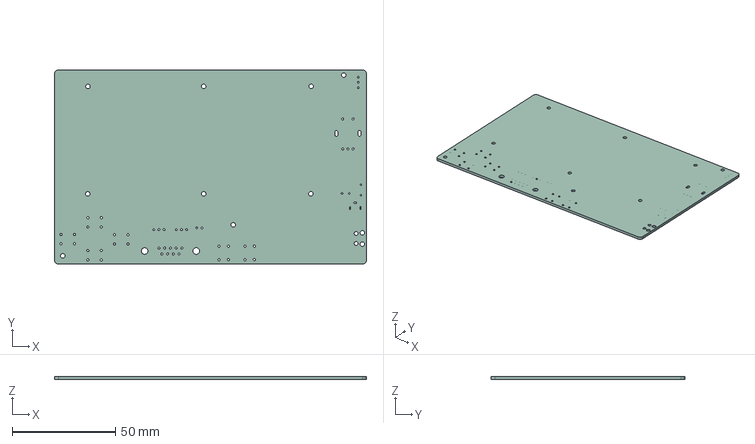
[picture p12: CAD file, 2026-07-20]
LED matrix error 2026 board only.step
151.0 x 94.0 x 1.51 mm

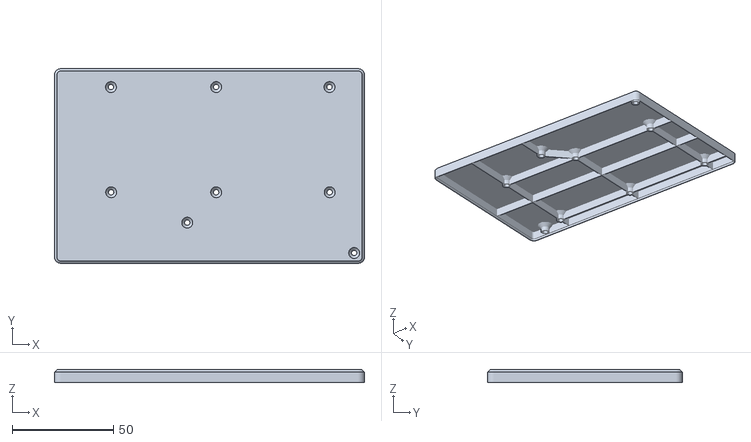
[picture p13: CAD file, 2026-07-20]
3D files/enclosure/bottom side^Assem5.STL
153.2 x 96.2 x 6.30

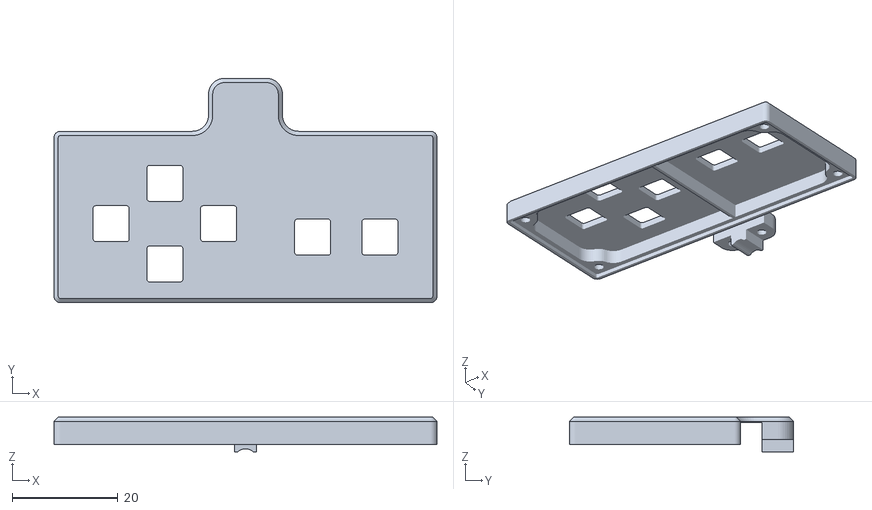
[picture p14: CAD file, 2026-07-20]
3D files/gamepad/top^gamepad.STL
72.4 x 42.4 x 6.60

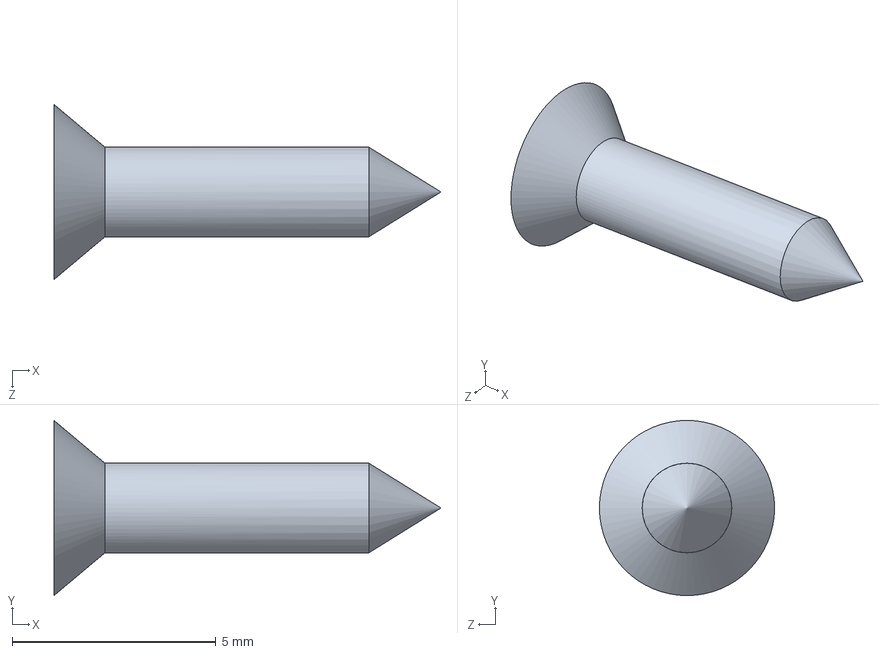
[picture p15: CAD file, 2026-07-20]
3D files/enclosure/Vrut; 2,2x9,5.SLDPRT
9.50 x 4.30 x 4.30 mm

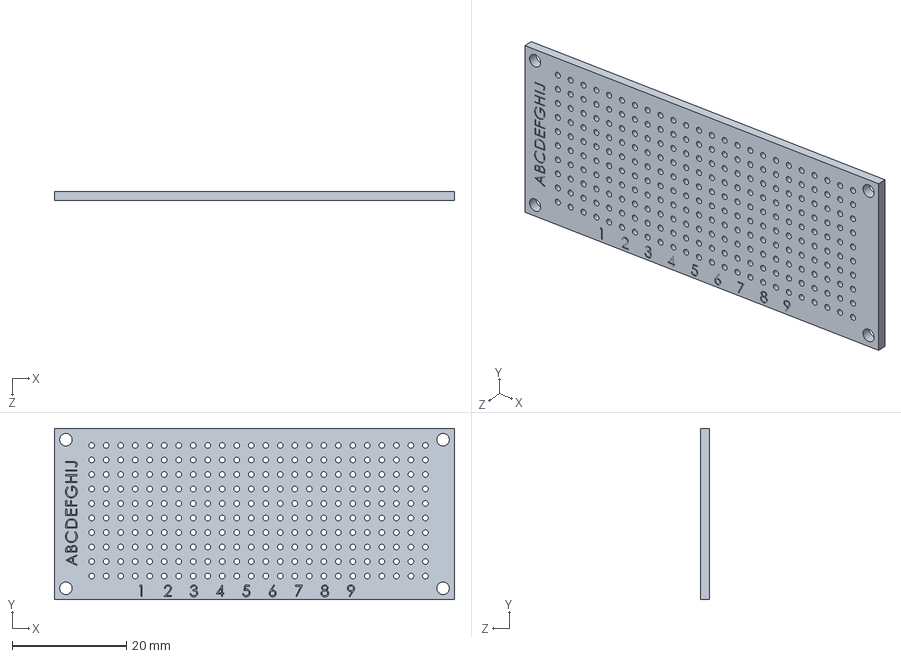
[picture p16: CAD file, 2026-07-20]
3D files/gamepad/Univerzální DPS 3x7cm, 240p.SLDPRT
70.0 x 30.0 x 1.60 mm

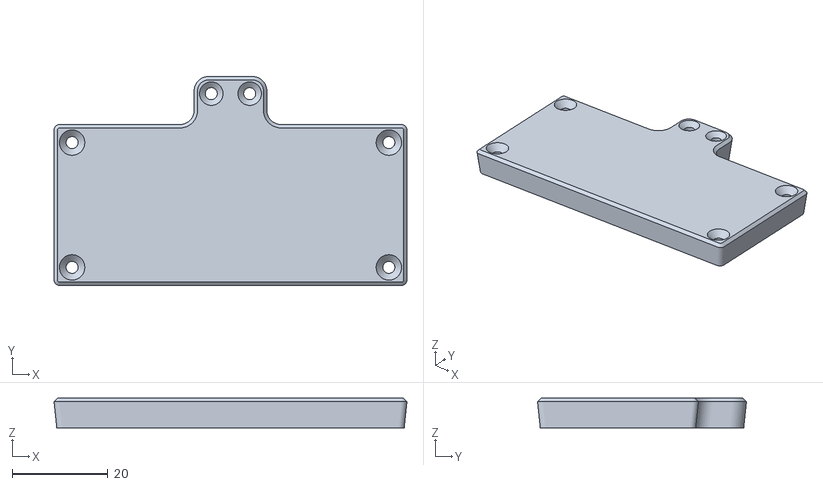
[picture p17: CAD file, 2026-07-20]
3D files/enclosure/bottom^gamepad.STL
73.6 x 43.6 x 6.20

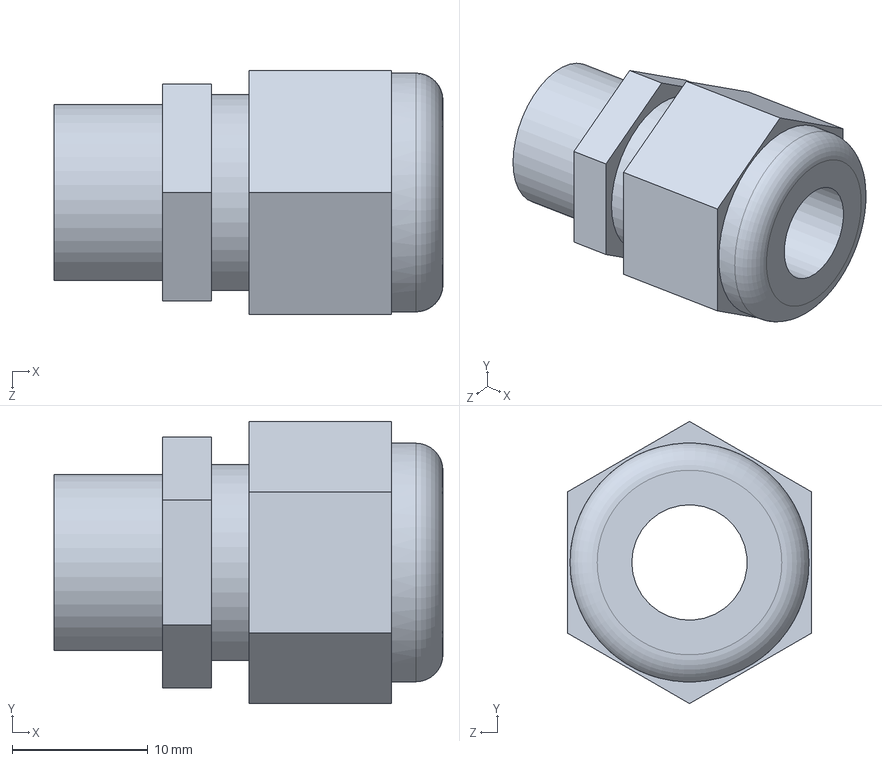
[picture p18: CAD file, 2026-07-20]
3D files/gamepad/PG-7 pruchodka.SLDPRT
28.7 x 20.8 x 18.0 mm

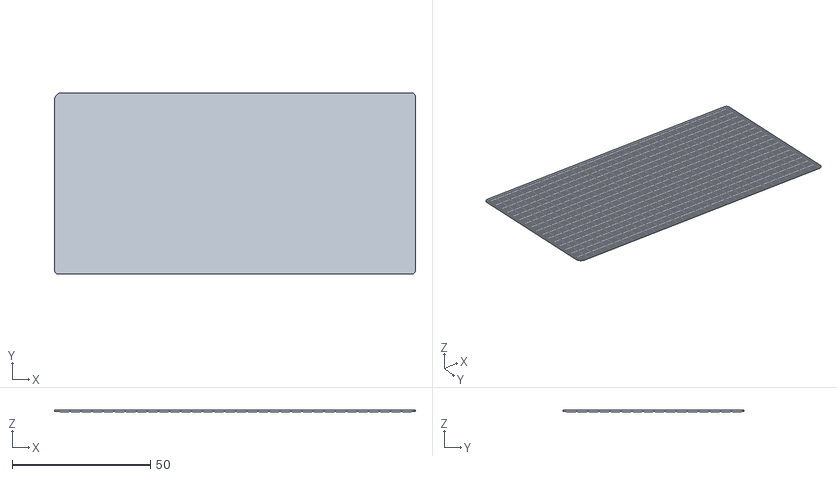
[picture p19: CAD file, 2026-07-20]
3D files/enclosure/diffuser^Assem5.STL
130.7 x 65.7 x 0.6

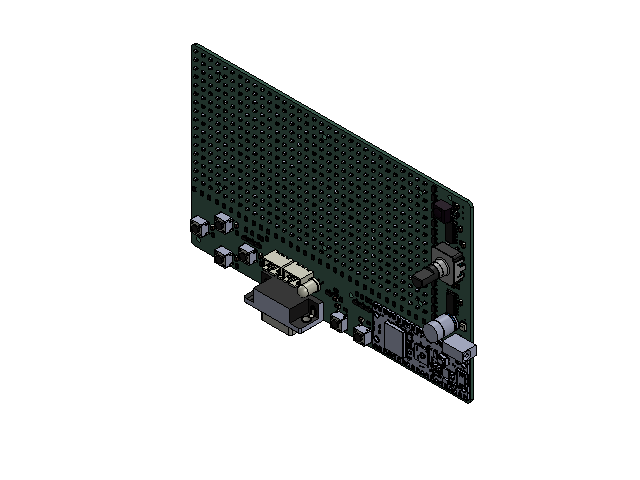
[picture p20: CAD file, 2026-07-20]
3D files/PCB asm/LED matrix error 2026.SLDASM
LED matrix error 2026 1.37.1
LED matrix error 2026 1.37.2
LED_0603_1608Metric x 512
EC12E20-24P24C-SW
R_0805_2012Metric x 59
C_0805_2012Metric x 20
SOT-23 x 23
JST_XH_B3B-XH-A_1x03_P2.50mm_Vertical x 2
SW_PUSH_6mm_H4.3mm x 6
CP_Radial_D8.0mm_P3.50mm
LED_D5.0mm_Clear
Vishay_MOLD-3Pin
SOIC-16_3.9x9.9mm_P1.27mm x 2
AMS_TSL2550_SMD
DSUB-9_Pins_Horizontal_P2.77x2.84mm_EdgePinOffset4.94mm_Housed_MountingHolesOffset4.94mm
SOT-223
SSOP-24_3.9x8.7mm_P0.635mm x 2
LED matrix error 2026_PCB
Part39^LED matrix error 2026

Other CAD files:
3D files/PCB asm/Raspberry_Pi_Pico_W.SLDASM
3D files/PCB asm/JST_XH_B3B-XH-A_1x03_P2.50mm_Vertical.SLDPRT
3D files/PCB asm/EC12E20-24P24C-SW.SLDPRT
3D files/PCB asm/AMS_TSL2550_SMD.SLDPRT
3D files/PCB asm/R_0805_2012Metric.SLDPRT
3D files/LED matrix error 2026 board only.STL
3D files/PCB asm/BarrelJack_GCT_DCJ200-10-A_Horizontal.SLDPRT
3D files/PCB asm/CP_Radial_D8.0mm_P3.50mm.SLDPRT
3D files/PCB asm/C_0805_2012Metric.SLDPRT
3D files/PCB asm/DSUB-9_Pins_Horizontal_P2.77x2.84mm_EdgePinOffset4.94mm_Housed_MountingHolesOffset4.94mm.SLDPRT
3D files/PCB asm/LED matrix error 2026 1.37.1.SLDPRT
3D files/PCB asm/LED matrix error 2026 1.37.2.SLDPRT
3D files/PCB asm/LED matrix error 2026_PCB.SLDPRT
3D files/PCB asm/LED_0603_1608Metric.SLDPRT
3D files/PCB asm/LED_D5.0mm_Clear.SLDPRT
3D files/PCB asm/SOIC-16_3.9x9.9mm_P1.27mm.SLDPRT
3D files/PCB asm/SOT-223.SLDPRT
3D files/PCB asm/SOT-23.SLDPRT
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

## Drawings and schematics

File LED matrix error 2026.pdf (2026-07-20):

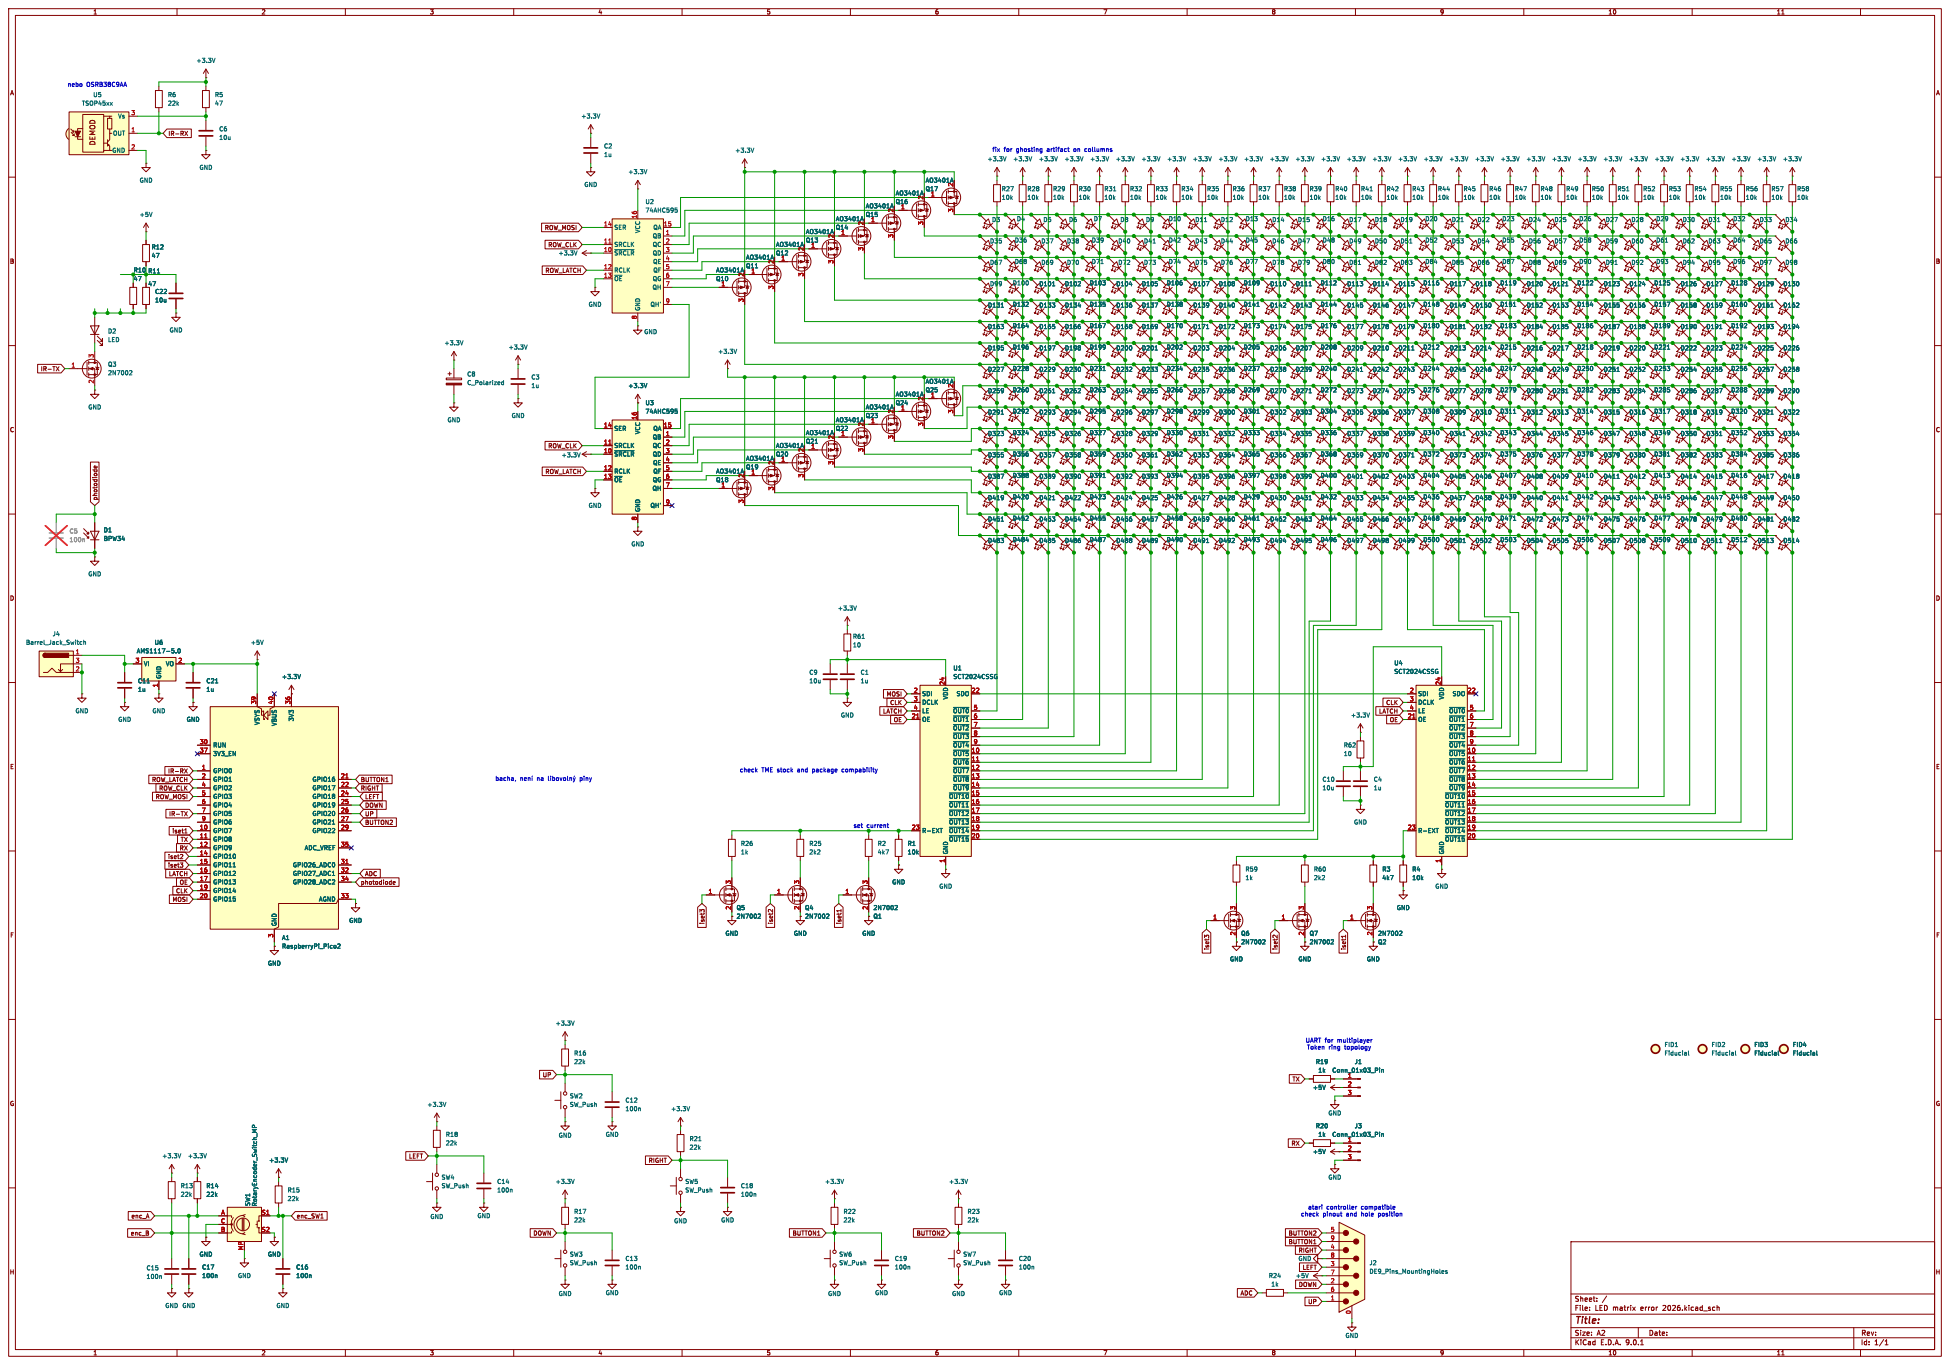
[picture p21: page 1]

3 3V3 36 GPIO16 21 GPIO17 22 GPIO18 24 GPIO19 25 GPIO20 26 GPIO21 27 GPIO22 29 ADC_VREF 35 GPIO26_ADC0 31 GPIO27_ADC1 32 GPIO28_ADC2 34 AGND 33 A1RaspberryPi_Pico2 GND GND GND GND GND GND

3 3V3 36 GPIO16 21 GPIO17 22 GPIO18 24 GPIO19 25 GPIO20 26 GPIO21 27 GPIO22 29 ADC_VREF 35 GPIO26_ADC0 31 GPIO27_ADC1 32 GPIO28_ADC2 34 AGND 33 GND GND GND GND

set current bacha, þÿnení na þÿlibovolný piny

check pinout and hole position

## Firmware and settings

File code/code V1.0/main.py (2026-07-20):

"""
Systém menu + multiplayer had + malování pro LED matici
========================================================
Importuje moduly led_matrix_pio, encoder, token_ring, ir_nec.
Spouští se jako main.py.

Ovládání menu:
  Otočení enkodéru = posun v položkách
  Stisk enkodéru   = potvrdit výběr
  Fire1 / Fire2    = potvrdit výběr
  Libovolné šipkové tlačítko = posun v položkách

Položky menu:
  SNAKE     - had pro jednoho hráče
  2P SNAKE  - had pro dva hráče přes token ring (propojení dvou zařízení)
  ATTRACT   - klidový/animační režim (šetřič displeje)
  PAINT     - volné malování na matici
  SETTINGS  - jas (enkodér) + info o ringu (propojení)
"""

import machine
import utime
import math

from led_matrix_pio import (
    start, stop,
    set_pixel, clear, fill, show,
    fill_rect, draw_rect,
    ROWS, COLS, _back,
)
from ir_nec import NEC, MatrixCurrent
from encoder import Encoder
from token_ring import TokenRing

# Fotodioda na GP28 - použije se pro automatický jas (SETTINGS: MAN/AUTO).
# Import obalený v try/except, aby hlavní program fungoval i bez ní.
try:
    from photodiode import read_raw as _photo_read_raw
except Exception:
    _photo_read_raw = None

_auto_brightness = False   # přepíná se v SETTINGS (MAN/AUTO)
_show_score_on_quit = True   # přepíná se v SETTINGS (SCORE PŘI KONCI)
_last_auto_check = 0

# ---------------------------------------------------------------------------
# Tlačítka (piny nastavené jako vstup s pull-up, tlačítko stisknuto = 0)
# ---------------------------------------------------------------------------
_BTN_FIRE1 = machine.Pin(16, machine.Pin.IN, machine.Pin.PULL_UP)
_BTN_RIGHT = machine.Pin(17, machine.Pin.IN, machine.Pin.PULL_UP)
_BTN_LEFT  = machine.Pin(18, machine.Pin.IN, machine.Pin.PULL_UP)
_BTN_DOWN  = machine.Pin(19, machine.Pin.IN, machine.Pin.PULL_UP)
_BTN_UP    = machine.Pin(20, machine.Pin.IN, machine.Pin.PULL_UP)
_BTN_FIRE2 = machine.Pin(21, machine.Pin.IN, machine.Pin.PULL_UP)

# Jednotlivé funkce vrací True, pokud je dané tlačítko právě stisknuté
def btn_left():  return _BTN_LEFT.value()  == 0
def btn_right(): return _BTN_RIGHT.value() == 0
def btn_up():    return _BTN_UP.value()    == 0
def btn_down():  return _BTN_DOWN.value()  == 0
def btn_fire1(): return _BTN_FIRE1.value() == 0
def btn_fire2(): return _BTN_FIRE2.value() == 0
def any_btn():   return (btn_left() or btn_right() or btn_up() or
                         btn_down() or btn_fire1() or btn_fire2())
def all_btn():   return (btn_left() and btn_right() and btn_up() and
                         btn_down() and btn_fire1() and btn_fire2())

def wait_no_buttons(enc=None, timeout_ms=2000):
    """Počká, dokud uživatel nepustí všechna tlačítka (max. timeout_ms),
    aby se jeden stisk neprovedl vícekrát za sebou."""
    t = utime.ticks_ms()
    while any_btn() or (enc and enc.pressed):
        if utime.ticks_diff(utime.ticks_ms(), t) > timeout_ms:
            break
        utime.sleep_ms(1)

class EncoderEdge:
    """
    Obal nad enkodérem, který dělá spolehlivou hranovou detekci stisku
    jeho tlačítka vlastním pollováním (žádné IRQ potřeba) - was_pressed()
    teď vrátí True jen jednou při skutečném stisku (přechod
    nestisknuto->stisknuto), a dokud se tlačítko drží, se znovu
    nespustí, dokud se nepustí a nestiskne znovu.

    Dřív se všude volalo was_pressed() přímo na hardwarové třídě, a
    občas se stalo, že hra hned po spuštění z menu sama skončila -
    stisk enkodéru použitý k potvrzení výběru v menu byl zřejmě ještě
    "aktivní", když hra hned po startu zkontrolovala, jestli se má
    ukončit. Tenhle obal to řeší tak, že hranu počítá sám z nezávisle
    dostupného syrového stavu (.pressed), místo aby se spoléhal na
    interní chování was_pressed() hardwarové třídy.
    """
    def __init__(self, raw_enc):
        self._enc = raw_enc
        self._prev_pressed = False

    def was_pressed(self):
        cur = bool(self._enc.pressed)
        edge = cur and not self._prev_pressed
        self._prev_pressed = cur
        return edge

    @property
    def pressed(self):
        return self._enc.pressed

    def delta(self):
        return self._enc.delta()

    @property
    def value(self):
        return self._enc.value

    @value.setter
    def value(self, v):
        self._enc.value = v

    def set_range(self, lo, hi, wrap=False):
        return self._enc.set_range(lo, hi, wrap=wrap)

class Buttons:
    """
    Přečte všech 6 tlačítek jednou za smyčku a vrátí jak jejich
    aktuální stav (drženo/nedrženo), tak "hranu" (bylo právě
    stisknuto v tomto kroku). Nahrazuje dřívější opakované
    sledování prev/edge stavu, které bylo duplikované v každém
    herním režimu zvlášť.
    """
    __slots__ = ('_prev',)

    def __init__(self):
        self._prev = {'up': False, 'down': False, 'left': False,
                       'right': False, 'fire1': False, 'fire2': False}

    def poll(self):
        """Vrátí dvojici (drženo, právě_stisknuto) pro všechna tlačítka."""
        cur = {
            'up':    btn_up(),    'down':  btn_down(),
            'left':  btn_left(),  'right': btn_right(),
            'fire1': btn_fire1(), 'fire2': btn_fire2(),
        }
        prev = self._prev
        edge = {k: cur[k] and not prev[k] for k in cur}
        self._prev = cur
        return cur, edge

# ---------------------------------------------------------------------------
# Testovací režim displeje
# ---------------------------------------------------------------------------
def run_test_mode():
    """
    Testovací režim displeje. Aktivuje se stiskem VŠECH 6 tlačítek zároveň
    (bez enkodéru) — vhodné pro rychlou kontrolu, že všechny LED a napájení
    fungují. Displej velmi rychle bliká celý naráz (ale ne tak rychle, aby
    to oko nepostřehlo — je to zjevný rychlý blikot/stroboskop).
    Stiskem JAKÉHOKOLIV tlačítka se test ukončí a program pokračuje přesně
    tam, odkud byl test spuštěn (v menu, ve hře, v malování, ...).
    Lze aktivovat kdykoliv, protože kontrola všech 6 tlačítek je zanořená
    do hlavních smyček všech režimů.
    """
    wait_no_buttons()   # nejdřív počkat, až uživatel pustí všech 6 tlačítek
    on = False
    while True:
        on = not on
        if on: fill()
        else:  clear()
        show()
        # čekání rozdělené na kratší kousky, aby reakce na stisk byla okamžitá
        for _ in range(3):
            if any_btn():
                clear(); show()
                wait_no_buttons()
                return
            utime.sleep_ms(10)

_current_ref = None   # nastaví main() - odkaz na MatrixCurrent pro auto jas

def _apply_auto_brightness():
    """
    Přepočítá jas podle fotodiody a rovnou ho nastaví.
    Syrová hodnota 3000 a méně = minimální jas, 7000 a víc = maximální,
    mezi tím lineární interpolace. Nemusí to být přesné, takže se
    počítá přes bitový posun místo skutečného dělení.
    """
    if _photo_read_raw is None or _current_ref is None:
        return
    try:
        raw = _photo_read_raw()
    except Exception:
        return
    if raw <= 3000:
        lvl = 0
    elif raw >= 7000:
        lvl = 7
    else:
        # (7000-3000) rozsah na 8 úrovní - zhruba 500 na úroveň, >>9 (512)
        # je dost blízko a je to jen bitový posun, ne dělení
        lvl = (raw - 3000) >> 9
        if lvl > 7: lvl = 7
        if lvl < 0: lvl = 0
    _current_ref.set_level(lvl)

def check_test_mode():
    """Pomocná funkce: pokud jsou stisklá všechna tlačítka, spustí test
    a vrátí True (volající smyčka pak má hned pokračovat dalším cyklem).
    Mimochodem (jednou za ~300ms) tady také přepočítá automatický jas,
    pokud je zapnutý - toto je jediné místo volané ze všech herních
    smyček, takže auto jas takhle funguje všude, ne jen v SETTINGS."""
    global _last_auto_check
    if _auto_brightness:
        now = utime.ticks_ms()
        if utime.ticks_diff(now, _last_auto_check) >= 300:
            _last_auto_check = now
            _apply_auto_brightness()
    if all_btn():
        run_test_mode()
        return True
    return False

# ---------------------------------------------------------------------------
# Obecný výběr z několika možností (obtížnost, herní režim apod.)
# ---------------------------------------------------------------------------
def _pick_option(enc, title, options, initial=0):
    """
    Obrazovka výběru z několika možností - používají ji všechny
    obrazovky "vyber si obtížnost/režim" před hrou.
      Šipky nahoru/dolů NEBO otočení enkodéru = změna volby
      Fire1/Fire2 nebo stisk enkodéru          = potvrzení
    Vrátí index vybrané možnosti.
    """
    sel = initial % len(options)
    btns = Buttons()
    wait_no_buttons(enc)
    if enc:
        enc.was_pressed()
    while True:
        if check_test_mode():
            continue
        cur, edge = btns.poll()
        if edge['up']:   sel = (sel - 1) % len(options)
        if edge['down']: sel = (sel + 1) % len(options)
        if enc:
            d = enc.delta()
            if d:
                sel = (sel + (1 if d > 0 else -1)) % len(options)
        if edge['fire1'] or edge['fire2'] or (enc and enc.was_pressed()):
            wait_no_buttons(enc)
            return sel
        clear()
        draw_text(title, col_start=(COLS - text_width(title)) // 2,
                   row_start=0, level=1)
        name = options[sel]
        draw_text(name, col_start=(COLS - text_width(name)) // 2,
                   row_start=8, level=2)
        show()
        utime.sleep_ms(20)

# ---------------------------------------------------------------------------
# Kompletní font (velká písmena + číslice + symboly), každý znak 3×5 bodů
# ---------------------------------------------------------------------------
_FONT = {
    ' ': [0b00000,0b00000,0b00000],
    '!': [0b00000,0b10111,0b00000],
    '-': [0b00100,0b00100,0b00100],
    '.': [0b00000,0b10000,0b00000],
    ':': [0b00000,0b01010,0b00000],
    '0': [0b11111,0b10001,0b11111],
    '1': [0b00000,0b11111,0b00000],
    '2': [0b11101,0b10101,0b10111],
    '3': [0b10101,0b10101,0b11111],
    '4': [0b00111,0b00100,0b11111],
    '5': [0b10111,0b10101,0b11101],
    '6': [0b11111,0b10101,0b11101],
    '7': [0b00001,0b00001,0b11111],
    '8': [0b11111,0b10101,0b11111],
    '9': [0b10111,0b10101,0b11111],
    'A': [0b11111,0b00101,0b11111],
    'B': [0b11111,0b10101,0b01010],
    'C': [0b11111,0b10001,0b10001],
    'D': [0b11111,0b10001,0b01110],
    'E': [0b11111,0b10101,0b10001],
    'F': [0b11111,0b00101,0b00001],
    'G': [0b11111,0b10001,0b11101],
    'H': [0b11111,0b00100,0b11111],
    'I': [0b00000,0b11111,0b00000],
    'J': [0b11000,0b10000,0b11111],
    'K': [0b11111,0b00100,0b11011],
    'L': [0b11111,0b10000,0b10000],
    'M': [0b11111,0b00110,0b11111],
    'N': [0b11111,0b00010,0b11111],
    'O': [0b11111,0b10001,0b11111],
    'P': [0b11111,0b00101,0b00111],
    'Q': [0b01111,0b01001,0b11111],
    'R': [0b11111,0b00101,0b11011],
    'S': [0b10111,0b10101,0b11101],
    'T': [0b00001,0b11111,0b00001],
    'U': [0b11111,0b10000,0b11111],
    'V': [0b01111,0b10000,0b01111],
    'W': [0b11111,0b01000,0b11111],
    'X': [0b11011,0b00100,0b11011],
    'Y': [0b00111,0b11100,0b00111],
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
}

def draw_char(ch, col_start, row_start=0, level=2):
    """Vykreslí jeden znak na danou pozici a vrátí sloupec pro další znak."""
    cols = _FONT.get(ch.upper(), _FONT[' '])
    for ci, mask in enumerate(cols):
        for ri in range(5):
            set_pixel(row_start + ri, col_start + ci, level if (mask >> ri) & 1 else 0)
    return col_start + 4   # pozice dalšího znaku (3 body široký + 1 mezera)

def draw_text(text, col_start=0, row_start=0, level=2):
    """Vykreslí celý text znak po znaku od dané pozice."""
    col = col_start
    for ch in text:
        col = draw_char(ch, col, row_start, level)
    return col

def text_width(text):
    """Vrátí šířku textu v bodech (pro vycentrování na displeji)."""
    return len(text) * 4 - 1   # 3 body + 1 mezera na znak, poslední mezera se nepočítá

# ---------------------------------------------------------------------------
# Pomocná funkce pro náhodné číslo (na Pi Pico používá urandom, jinak náhradní generátor)
# ---------------------------------------------------------------------------
try:
    import urandom
    def _randint(a, b): return urandom.randint(a, b)
except ImportError:
    _seed = 12345
    def _randint(a, b):
        global _seed
        _seed = (_seed * 1103515245 + 12345) & 0x7FFFFFFF
        return a + (_seed % (b - a + 1))

# ---------------------------------------------------------------------------
# Zobrazení skóre / blikání celé matice / odpočet před hrou
# ---------------------------------------------------------------------------
def show_score(score, row_start=5):
    """Zobrazí skóre, které 4× blikne (vycentrované na displeji)."""
    for _ in range(4):
        clear()
        draw_text(str(score), col_start=max(0, (COLS - text_width(str(score))) // 2),
                  row_start=row_start)
        show()
        utime.sleep_ms(300)
        clear(); show()
        utime.sleep_ms(150)

def blink_all(times=3, on_ms=120, off_ms=80):
    """Rozbliká celou matici (např. po konci hry)."""
    for _ in range(times):
        fill(); show(); utime.sleep_ms(on_ms)
        clear(); show(); utime.sleep_ms(off_ms)

def _end_game_flash(score, times=3, on_ms=120, off_ms=80):
    """
    Po konci jednohráčské hry - bliknutí celé matice a zobrazení skóre,
    ale jen pokud je to v SETTINGS zapnuté ("SCORE PŘI KONCI"). Když je
    to vypnuté, hra prostě skončí potichu bez blikání a bez ukázání
    skóre.
    """
    if _show_score_on_quit:
        blink_all(times, on_ms, off_ms)
        show_score(score)

def countdown():
    """Odpočet 3, 2, 1 před začátkem hry."""
    for n in (3, 2, 1):
        clear()
        draw_text(str(n), col_start=14, row_start=5, level=2)
        show(); utime.sleep_ms(600)
        clear(); show(); utime.sleep_ms(100)

# ---------------------------------------------------------------------------
# IR dálkové ovládání (kódy tlačítek dálkového ovladače)
# ---------------------------------------------------------------------------
IR_CMD_UP    = 0x0b
IR_CMD_DOWN  = 0x0f
IR_CMD_LEFT  = 0x49
IR_CMD_RIGHT = 0x4a
IR_CMD_OK    = 0x0D
IR_CMD_STAR  = 0x01   # hvězdička = ztlumit
IR_CMD_HASH  = 0x0a   # mřížka    = zesvětlit

def process_ir(ir, current, ir_state):
    """Přečte přijaté IR příkazy a promítne je do jasu / směru pohybu."""
    while True:
        r = ir.poll()
        if r is None:
            break
        addr, cmd, repeat = r
        if repeat:
            continue   # opakovaný kód při podrženém tlačítku ignorujeme
        if cmd == IR_CMD_STAR:
            current.step_down()
        elif cmd == IR_CMD_HASH:
            current.step_up()
        elif cmd == IR_CMD_LEFT:  ir_state['dir'] = -1
        elif cmd == IR_CMD_UP:    ir_state['dir'] = -1
        elif cmd == IR_CMD_RIGHT: ir_state['dir'] =  1
        elif cmd == IR_CMD_DOWN:  ir_state['dir'] =  1
        ir_state['cmd'] = cmd

# ---------------------------------------------------------------------------
# Hlavní menu
# ---------------------------------------------------------------------------
MENU_ITEMS = [
    "SNAKE",
    "2P SNAKE",
    "LIFE",
    "BREAKOUT",
    "2P PONG",
    "FLAPPY",
    "GALAGA",
    "ASTEROID",
    "FROGGER",
    "REACTION",
    "MISSILE",
    "RACER",
    "2P TRON",
    "TREX",
    "ELEVATOR",
    "ELEV2",
    "ATTRACT",
    "PAINT",
    "TIME",
    "STOPWCH",
    "BTN TEST",
    "SETTINGS",
    "INFO",
]

def draw_menu(selected, scroll_offset):
    """
    Vykreslí položky menu na displeji 16×32.
    Naráz jsou vidět 3 položky (řádky 0-4, 6-10, 11-15).
    Vybraná položka svítí na úrovni 2, ostatní na úrovni 1.
    Šipky vpravo ukazují, že lze menu posunout dál nahoru/dolů.
    """
    clear()
    visible = 3
    row_positions = [0, 6, 11]

    for vi in range(visible):
        item_idx = scroll_offset + vi
        if item_idx >= len(MENU_ITEMS):
            break
        label   = MENU_ITEMS[item_idx]
        level   = 2 if item_idx == selected else 1
        row     = row_positions[vi]
        draw_text(label, col_start=1, row_start=row, level=level)

    # Šipka nahoru, pokud lze menu posunout výš
    if scroll_offset > 0:
        set_pixel(0, 30, 2)
        set_pixel(1, 31, 2)
        set_pixel(1, 29, 2)

    # Šipka dolů, pokud lze menu posunout níž
    if scroll_offset + visible < len(MENU_ITEMS):
        set_pixel(15, 30, 2)
        set_pixel(14, 31, 2)
        set_pixel(14, 29, 2)

    # Kurzor výběru: jasná tečka vlevo od vybrané položky
    vi_sel = selected - scroll_offset
    if 0 <= vi_sel < visible:
        set_pixel(row_positions[vi_sel] + 2, 0, 2)

    show()

def run_menu(enc, ir, current, ir_state, initial_selected=0):
    """
    Spustí smyčku menu. Vrátí index vybrané položky.
    Otočení enkodéru posouvá výběr, stisk enkodéru / fire1 / fire2 potvrdí.
    `initial_selected` - položka, na které se má kurzor objevit (aby se po
    návratu ze hry menu neotevíralo vždy znovu od SNAKE, ale tam, kde
    hráč naposledy skončil).
    """
    selected      = max(0, min(initial_selected, len(MENU_ITEMS) - 1))
    visible       = 3
    scroll_offset = 0
    if selected >= visible:
        scroll_offset = min(selected - visible + 1, len(MENU_ITEMS) - visible)
    prev_enc      = enc.value

    wait_no_buttons(enc)
    if enc:
        enc.was_pressed()   # zahodit "zaseknutý" stisk enkodéru, který mohl
                             # zůstat nespotřebovaný z předchozí hry (pokud
                             # hra sama enc.was_pressed() nikdy nečetla,
                             # jinak by tenhle stisk hned "potvrdil" SNAKE)
    enc.set_range(0, len(MENU_ITEMS) - 1, wrap=True)
    enc.value = selected

    draw_menu(selected, scroll_offset)

    while True:
        if check_test_mode():
            continue

        process_ir(ir, current, ir_state)
        ir_state['dir'] = None

        # Otočení enkodéru = posun výběru
        new_val = enc.value
        if new_val != prev_enc:
            selected = new_val
            if selected < scroll_offset:
                scroll_offset = selected
            elif selected >= scroll_offset + visible:
                scroll_offset = selected - visible + 1
            prev_enc = new_val
            draw_menu(selected, scroll_offset)

        # Šipka nahoru/vlevo = předchozí položka
        if btn_up() or btn_left():
            selected = (selected - 1) % len(MENU_ITEMS)
            enc.value = selected
            prev_enc = selected
            if selected < scroll_offset:
                scroll_offset = selected
            draw_menu(selected, scroll_offset)
            wait_no_buttons(enc)

        # Šipka dolů/vpravo = další položka
        elif btn_down() or btn_right():
            selected = (selected + 1) % len(MENU_ITEMS)
            enc.value = selected
            prev_enc = selected
            if selected >= scroll_offset + visible:
                scroll_offset = selected - visible + 1
            draw_menu(selected, scroll_offset)
            wait_no_buttons(enc)

        # Potvrzení výběru
        elif btn_fire1() or btn_fire2() or enc.was_pressed():
            wait_no_buttons(enc)
            return selected

        utime.sleep_ms(10)
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

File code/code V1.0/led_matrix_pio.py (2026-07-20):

"""
16x32 LED Matrix Driver for RP2040 – PIO, 3-level grayscale
=============================================================
Pin assignments:
  Row: row_mosi=GP3  row_clk=GP2  row_latch=GP1
  Col: col_mosi=GP15 col_clk=GP14 col_latch=GP12 col_OE=GP13 (active LOW)

Grayscale model
---------------
3 brightness levels per pixel:
  0 = off
  1 = 50% brightness  (on in every other frame)
  2 = 100% brightness (on in every frame)

Implementation:
  Two framebuffers maintained internally:
    _full   — bitmask of ALL lit pixels (level 1 + level 2)
    _bright — bitmask of FULL brightness pixels (level 2 only)

  fill_fifo() alternates which buffer it sends each call:
    even calls → send _full   (level 1 + level 2 both on)
    odd calls  → send _bright (only level 2 on)

  Result:
    level 2 pixel: on in both frames → 100% duty cycle
    level 1 pixel: on in even frames only → 50% duty cycle
    level 0 pixel: off in both frames → 0%

  Frame rate is high enough (~330Hz) that 50% flicker is invisible.

PIO programs are identical to the proven working version.
SM0: col shift + col_latch + OE (set pins GP12, GP13)
SM1: row shift + row_latch      (set pin  GP1)

Ghosting prevention: SM1 called twice per row —
  first with all-1s (deselect all rows), then with real row selector.

Usage:
  from led_matrix_pio import *
  start()
  set_pixel(0, 0, 2)   # full brightness
  set_pixel(0, 1, 1)   # half brightness
  set_pixel(0, 2, 0)   # off
  show()
  while True:
      fill_fifo()
"""

import machine
import utime
import rp2
import array
from micropython import const

# ---------------------------------------------------------------------------
# Pins
# ---------------------------------------------------------------------------
ROW_MOSI  = const(3)
ROW_CLK   = const(2)
ROW_LATCH = const(1)
COL_MOSI  = const(15)
COL_CLK   = const(14)
COL_LATCH = const(12)
COL_OE    = const(13)
ROWS      = const(16)
COLS      = const(32)

_ROW_BLANK = const(0xFFFF0000)   # all rows deselected

# ---------------------------------------------------------------------------
# Back buffer — _back[row][col] = 0, 1, or 2
# ---------------------------------------------------------------------------
_back = [[0] * COLS for _ in range(ROWS)]

# Internal front buffers — rebuilt by show()
# _full[row]   = bitmask of pixels with level >= 1 (shown every frame)
# _bright[row] = bitmask of pixels with level == 2 (shown every other frame)
_full   = array.array('I', [0] * ROWS)
_bright = array.array('I', [0] * ROWS)

# Row selector words
_row_sel = array.array('I', [
    ((0xFFFF ^ (0x8000 >> i)) & 0xFFFF) << 16
    for i in range(ROWS)
])

# Which frame are we on — alternates each fill_fifo() call
_frame_toggle = 0

# ---------------------------------------------------------------------------
# Public pixel API
# ---------------------------------------------------------------------------
def set_pixel(row, col, level=2):
    """Set pixel brightness: 0=off, 1=half, 2=full."""
    if 0 <= row < ROWS and 0 <= col < COLS:
        _back[ROWS - 1 - row][col] = max(0, min(2, int(level)))

def get_pixel(row, col):
    if 0 <= row < ROWS and 0 <= col < COLS:
        return _back[ROWS - 1 - row][col]
    return 0

def clear():
    for r in range(ROWS):
        for c in range(COLS): _back[r][c] = 0

def fill(level=2):
    for r in range(ROWS):
        for c in range(COLS): _back[r][c] = level

def show():
    """
    Recompute _full and _bright from back buffer.
    Call after drawing, before fill_fifo().
    """
    for r in range(ROWS):
        row  = _back[r]
        full = 0
        brt  = 0
        for c in range(COLS):
            bit = 1 << c
            v   = row[c]
            if v >= 1: full |= bit
            if v >= 2: brt  |= bit
        _full[r]   = full
        _bright[r] = brt

# ---------------------------------------------------------------------------
# Drawing helpers
# ---------------------------------------------------------------------------
def draw_hline(row, col, w, level=2):
    for c in range(col, min(col + w, COLS)):
        set_pixel(row, c, level)

def draw_vline(col, row, h, level=2):
    for r in range(row, min(row + h, ROWS)):
        set_pixel(r, col, level)

def draw_rect(row, col, h, w, level=2):
    draw_hline(row,         col, w, level)
    draw_hline(row + h - 1, col, w, level)
    draw_vline(col,         row, h, level)
    draw_vline(col + w - 1, row, h, level)

def fill_rect(row, col, h, w, level=2):
    for r in range(row, min(row + h, ROWS)):
        for c in range(col, min(col + w, COLS)):
            set_pixel(r, c, level)

def scroll_left(n=1):
    for r in range(ROWS):
        row = _back[r]
        _back[r] = row[n:] + row[:n]

def scroll_right(n=1):
    for r in range(ROWS):
        row = _back[r]
        _back[r] = row[-n:] + row[:-n]

# ---------------------------------------------------------------------------
# PIO SM0 – col shift + col_latch + OE
# set_base = GP12: bit0=col_latch, bit1=OE
#
# set(pins, 0b10) → OE=1 (blank),   col_latch=0
# set(pins, 0b11) → OE=1 (blank),   col_latch=1  (latch pulse)
# set(pins, 0b00) → OE=0 (enabled), col_latch=0
# ---------------------------------------------------------------------------
@rp2.asm_pio(
    out_init     = (rp2.PIO.OUT_LOW,),
    sideset_init = (rp2.PIO.OUT_LOW,),
    set_init     = (rp2.PIO.OUT_LOW, rp2.PIO.OUT_HIGH),  # OE starts HIGH (disabled)
    out_shiftdir = rp2.PIO.SHIFT_LEFT,
    autopull     = False,
)
def col_program():
    wrap_target()

    # Blank
    set(pins, 0b10)                         # OE=1, col_latch=0

    # Blank row: tell SM1 to shift all-1s then latch
    irq(noblock, 4)
    wait(1, irq, 5)

    # Shift 32 col bits
    pull(block)                             # stall here if FIFO empty (OE already off)
    set(x, 31)
    label("col_loop")
    out(pins, 1)            .side(0)
    jmp(x_dec, "col_loop")  .side(1)
    nop()                   .side(0)

    # Latch col
    set(pins, 0b11)                         # col_latch=1, OE=1
    set(pins, 0b10)                         # col_latch=0, OE=1

    # Real row: tell SM1 to shift row selector then latch
    irq(noblock, 4)
    wait(1, irq, 5)

    # Enable display
    set(pins, 0b00)                         # OE=0 (enabled)

    # Hold delay ~256µs: 4× faster frame rate for flicker-free grayscale
    # 8MHz clock, inner loop: jmp[7] = 8 cycles = 1µs × 32 iters = 32µs
    # outer loop: 8 × 32µs = ~256µs → frame=4ms → grayscale flip=122Hz
    set(y, 7)
    label("delay_outer")
    set(x, 31)
    label("delay_inner")
    jmp(x_dec, "delay_inner") [7]
    jmp(y_dec, "delay_outer")

    wrap()
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

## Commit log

2026-07-20 initial upload
    [AMS_TSL2550_SMD.SLDPRT, BarrelJack_GCT_DCJ200-10-A_Horizontal.SLDPRT, CP_Radial_D8.0mm_P3.50mm.SLDPRT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]
2026-07-21 Add image documentation to README
    Added image documentation for the device.
2026-07-21 Revise hardware documentation and confirm pin connections
    Updated hardware documentation to confirm pin connections and list missing elements.
